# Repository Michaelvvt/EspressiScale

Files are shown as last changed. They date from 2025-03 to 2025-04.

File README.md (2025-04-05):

# EspressiScale

EspressiScale is a minimalist and affordable espresso scale designed to provide accurate measurements along with a built-in timer – perfect for both home and small coffee shop use.

## Features

- **Accurate Weighing:** Provides precise measurements for your espresso brewing.
- **Built-in Timer:** Monitors brewing time to ensure optimal extraction.
- **Minimalist Design:** A simple and modern solution focusing on essential features.
- **Bluetooth Connectivity:** Connect to Gaggiuino or other compatible devices to stream weight and timer data.

## Makerworld
This was also published on [makerworld](https://makerworld.com/en/models/1212476-espressiscale-small-minimalist-espresso-scale#profileId-1227630) for easy 3D printing.

## Bill of Materials (BOM)

| Quantity | Component | Details/Notes |
|---|---|---|
| 1 | [Lilygo T-Touch bar](https://lilygo.cc/products/t-touch-bar?variant=42880705102005) | |
| 1 | Battery | Any 3.7v rechargeable lithium battery (<10x34x48) |
| 1 | [500g Load Cell](https://www.aliexpress.com/item/1005006390450639.html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) | |
| 1 | [HX711](https://www.aliexpress.com/item/1005006293368575.html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) | High precision (available on AliExpress) |
|1 | [USB type C port](https://a.aliexpress.com/_EyspPbK) | Not yet implimented
| 4 | [M3x3.0 Threaded Inserts](https://cnckitchen.store/products/heat-set-insert-m3-x-3-short-version-100-pieces) | (I used CNCkitchen) |
| 2 | M3x10 Screws | |
| 2 | M3x12 Screws | |
| 2 | M3x12 Countersunk Screws | |
| - | Heat Shrink | |

### Optional Components

| Quantity | Component | Details/Notes |
|---|---|---|
| 2 | Extra Heated Inserts | |
| 2 | M3x6 Screws | |

## Installation

1. **PlatformIO setup in Visual Studio:**

   Make sure you have PlatformIO installed in Visual Studio. You'll also need espressif platform installed.
   
3. **Clone the repository:**

   ```bash
   git clone https://github.com/whauu/EspressiScale.git

4. **Navigate to the project folder**

   ```bash
   cd EspressiScale

5. **Open project in PlatformIO**
   
6. **Erase flash**
   
7. **Build filesystem**
   
8. **Upload filesystem**
   
9. **Build**

10. **Upload**

## Usage
**Touch controls:**
- **Left Display:** Starts and stops timer
- **Right Display:** Tares weight and resets timer
  
**Power:**
  - Touch the display anywhere to wake it up
  - The scale will automatically enter deep sleep after 5min with no use

**Bluetooth:**
  - The scale automatically advertises as "EspressiScale" via Bluetooth
  - Compatible with Gaggiuino using the esp-arduino-ble-scales library
  - You can remotely tare the scale, start/stop/reset the timer, and receive weight and timer data

**Update:**
   - Update using "scaleIP"/update
   - Build updated project
   - Upload the firmware.bin file
     <p align="center">
<img src="https://github.com/user-attachments/assets/cd5b869b-26ec-4d18-aa3c-554c78ec7306" alt="Screenshot" />
</p>

[PrettyOTA](https://github.com/LostInCompilation/PrettyOTA.git)

## Gaggiuino Integration

To integrate with Gaggiuino:

1. Make sure your Gaggiuino firmware includes the [esp-arduino-ble-scales](https://github.com/kstam/esp-arduino-ble-scales) library
2. Add the EspressiScale plugin to your Gaggiuino project by copying:
   - `esp-arduino-ble-scales/src/scales/espressiscale.h`
   - `esp-arduino-ble-scales/src/scales/espressiscale.cpp`
3. Add the following to your Gaggiuino initialization code:
   ```cpp
   #include "scales/espressiscale.h"
   
   void setup() {
     // ... other initialization code
     
     // Register the EspressiScale plugin
     EspressiScalesPlugin::apply();
     
     // ... other setup code
   }
   ```
4. Now your Gaggiuino should be able to automatically discover and connect to your EspressiScale

## License
This project is licensed under the MIT License

## Contact
If you have any questions or suggestions, you can:
- Open an issue in the GitHub repository
- Contact me directly at [whauu@espressiscale.com]

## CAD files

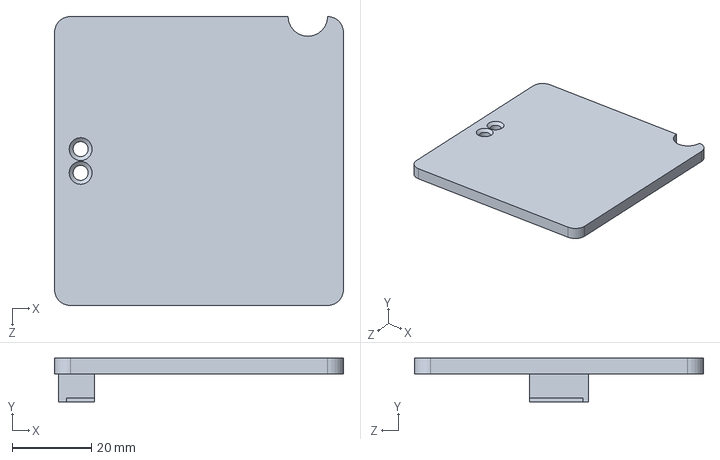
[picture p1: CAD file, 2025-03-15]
3D files/Vekt_innmat.SLDPRT
73.0 x 11.0 x 73.0 mm

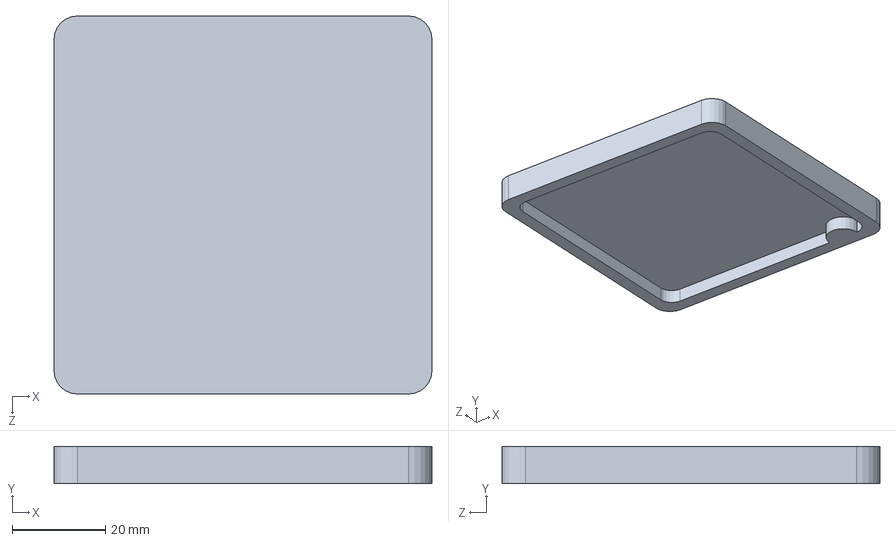
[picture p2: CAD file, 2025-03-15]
3D files/Vekt_mold.SLDPRT
81.0 x 8.00 x 81.0 mm

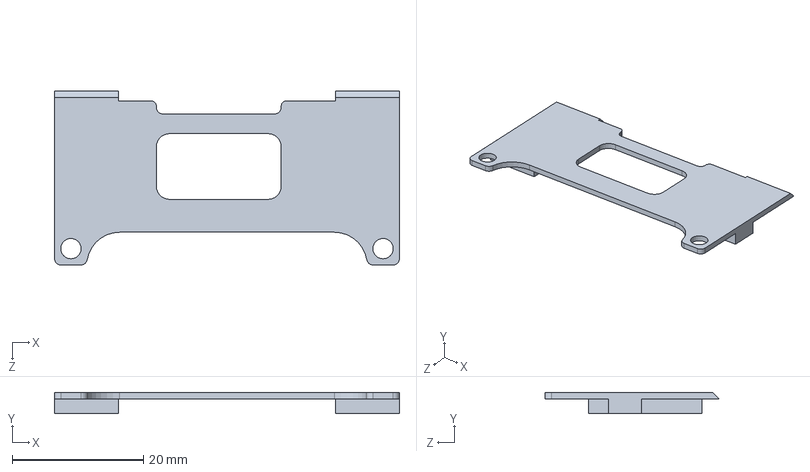
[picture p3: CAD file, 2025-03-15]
3D files/Vekt_bracket.SLDPRT
52.5 x 3.20 x 26.5 mm

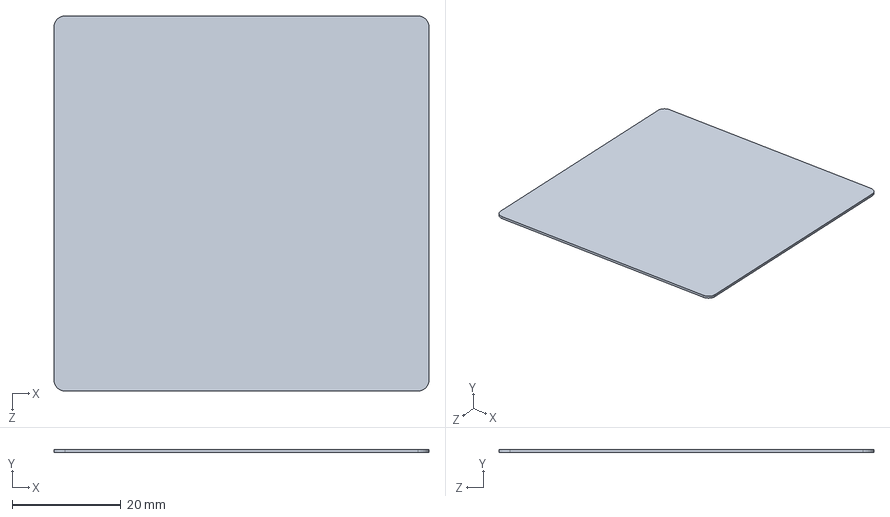
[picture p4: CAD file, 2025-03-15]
3D files/Vekt_matte.SLDPRT
69.0 x 0.6 x 69.0 mm

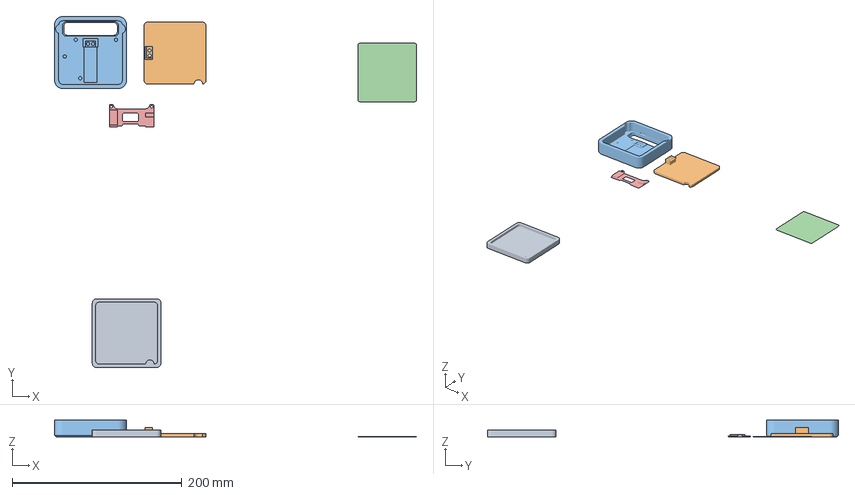
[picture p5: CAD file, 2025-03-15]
3D files/EspressiScale.3mf
426.7 x 413.7 x 20.0 mm
vekt_mould
innmat
Vekt_skall
weight_underpad
latch

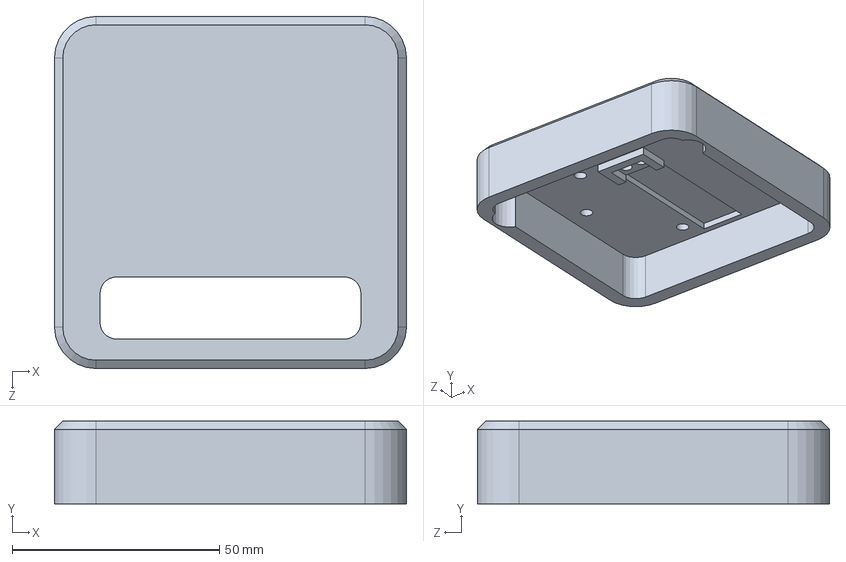
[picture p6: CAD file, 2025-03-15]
3D files/Vekt_skall.SLDPRT
85.0 x 20.0 x 85.0 mm

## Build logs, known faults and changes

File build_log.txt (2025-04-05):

Processing esp32s3box (platform: espressif32; board: esp32s3box; framework: arduino; lib_deps: bogde/HX711@^0.7.5, https://github.com/tzapu/WiFiManager.git, lostincompilation/PrettyOTA@^1.0.2, h2zero/NimBLE-Arduino@^1.4.1; monitor_speed: 921600; board_build.filesystem: littlefs; board_build.partitions: min_spiffs.csv)
--------------------------------------------------------------------------------
CONFIGURATION: https://docs.platformio.org/page/boards/espressif32/esp32s3box.html
PLATFORM: Espressif 32 (6.10.0) > Espressif ESP32-S3-Box
HARDWARE: ESP32S3 240MHz, 320KB RAM, 16MB Flash
DEBUG: Current (cmsis-dap) External (cmsis-dap, esp-bridge, esp-builtin, esp-prog, iot-bus-jtag, jlink, minimodule, olimex-arm-usb-ocd, olimex-arm-usb-ocd-h, olimex-arm-usb-tiny-h, olimex-jtag-tiny, tumpa)
PACKAGES: 
 - framework-arduinoespressif32 @ 3.20017.241212+sha.dcc1105b 
 - tool-esptoolpy @ 1.40501.0 (4.5.1) 
 - toolchain-riscv32-esp @ 8.4.0+2021r2-patch5 
 - toolchain-xtensa-esp32s3 @ 8.4.0+2021r2-patch5
LDF: Library Dependency Finder -> https://bit.ly/configure-pio-ldf
LDF Modes: Finder ~ chain, Compatibility ~ soft
Found 42 compatible libraries
Scanning dependencies...
Warning: Ignored `ESPAsyncWebServer` dependency for `PrettyOTA` library
Warning: Ignored `AsyncTCP` dependency for `ESPAsyncWebServer` library
Warning: Ignored `ESPAsyncTCP` dependency for `ESPAsyncWebServer` library
Warning: Ignored `Hash` dependency for `ESPAsyncWebServer` library
Warning: Ignored `RPAsyncTCP` dependency for `ESPAsyncWebServer` library
Dependency Graph
|-- HX711 @ 0.7.5 (License: Unknown, Path: /Users/michaelvvt/Coffee Project/EspressiScale/.pio/libdeps/esp32s3box/HX711)
|-- WiFiManager @ 2.0.17+sha.32655b7 (License: Unknown, URI: git+https://github.com/tzapu/WiFiManager.git, Path: /Users/michaelvvt/Coffee Project/EspressiScale/.pio/libdeps/esp32s3box/WiFiManager)
|   |-- DNSServer @ 2.0.0 (License: Unknown, Path: /Users/michaelvvt/.platformio/packages/framework-arduinoespressif32/libraries/DNSServer)
|   |   |-- WiFi @ 2.0.0 (License: Unknown, Path: /Users/michaelvvt/.platformio/packages/framework-arduinoespressif32/libraries/WiFi)
|   |-- ESPmDNS @ 2.0.0 (License: Unknown, Path: /Users/michaelvvt/.platformio/packages/framework-arduinoespressif32/libraries/ESPmDNS)
|   |   |-- WiFi @ 2.0.0 (License: Unknown, Path: /Users/michaelvvt/.platformio/packages/framework-arduinoespressif32/libraries/WiFi)
|   |-- Update @ 2.0.0 (License: Unknown, Path: /Users/michaelvvt/.platformio/packages/framework-arduinoespressif32/libraries/Update)
|   |-- WebServer @ 2.0.0 (License: Unknown, Path: /Users/michaelvvt/.platformio/packages/framework-arduinoespressif32/libraries/WebServer)
|   |   |-- WiFi @ 2.0.0 (License: Unknown, Path: /Users/michaelvvt/.platformio/packages/framework-arduinoespressif32/libraries/WiFi)
|   |   |-- FS @ 2.0.0 (License: Unknown, Path: /Users/michaelvvt/.platformio/packages/framework-arduinoespressif32/libraries/FS)
|   |-- WiFi @ 2.0.0 (License: Unknown, Path: /Users/michaelvvt/.platformio/packages/framework-arduinoespressif32/libraries/WiFi)
|-- PrettyOTA @ 1.0.6 (License: MIT, Path: /Users/michaelvvt/Coffee Project/EspressiScale/.pio/libdeps/esp32s3box/PrettyOTA)
|   |-- ArduinoJson @ 7.3.1 (License: Unknown, Path: /Users/michaelvvt/Coffee Project/EspressiScale/.pio/libdeps/esp32s3box/ArduinoJson)
|   |-- ArduinoOTA @ 2.0.0 (License: Unknown, Path: /Users/michaelvvt/.platformio/packages/framework-arduinoespressif32/libraries/ArduinoOTA)
|   |   |-- Update @ 2.0.0 (License: Unknown, Path: /Users/michaelvvt/.platformio/packages/framework-arduinoespressif32/libraries/Update)
|   |   |-- WiFi @ 2.0.0 (License: Unknown, Path: /Users/michaelvvt/.platformio/packages/framework-arduinoespressif32/libraries/WiFi)
|   |   |-- ESPmDNS @ 2.0.0 (License: Unknown, Path: /Users/michaelvvt/.platformio/packages/framework-arduinoespressif32/libraries/ESPmDNS)
|   |   |   |-- WiFi @ 2.0.0 (License: Unknown, Path: /Users/michaelvvt/.platformio/packages/framework-arduinoespressif32/libraries/WiFi)
|   |-- AsyncTCP @ 3.3.8 (License: LGPL-3.0, Path: /Users/michaelvvt/Coffee Project/EspressiScale/.pio/libdeps/esp32s3box/AsyncTCP)
|   |-- ESPAsyncWebServer @ 3.7.4 (License: LGPL-3.0, Path: /Users/michaelvvt/Coffee Project/EspressiScale/.pio/libdeps/esp32s3box/ESPAsyncWebServer)
|   |   |-- AsyncTCP @ 3.3.8 (License: LGPL-3.0, Path: /Users/michaelvvt/Coffee Project/EspressiScale/.pio/libdeps/esp32s3box/AsyncTCP)
|   |   |-- FS @ 2.0.0 (License: Unknown, Path: /Users/michaelvvt/.platformio/packages/framework-arduinoespressif32/libraries/FS)
|   |   |-- WebServer @ 2.0.0 (License: Unknown, Path: /Users/michaelvvt/.platformio/packages/framework-arduinoespressif32/libraries/WebServer)
|   |   |   |-- WiFi @ 2.0.0 (License: Unknown, Path: /Users/michaelvvt/.platformio/packages/framework-arduinoespressif32/libraries/WiFi)
|   |   |   |-- FS @ 2.0.0 (License: Unknown, Path: /Users/michaelvvt/.platformio/packages/framework-arduinoespressif32/libraries/FS)
|   |   |-- WiFi @ 2.0.0 (License: Unknown, Path: /Users/michaelvvt/.platformio/packages/framework-arduinoespressif32/libraries/WiFi)
|   |   |-- ArduinoJson @ 7.3.1 (License: Unknown, Path: /Users/michaelvvt/Coffee Project/EspressiScale/.pio/libdeps/esp32s3box/ArduinoJson)
|-- NimBLE-Arduino @ 1.4.3 (License: Unknown, Path: /Users/michaelvvt/Coffee Project/EspressiScale/.pio/libdeps/esp32s3box/NimBLE-Arduino)
|-- lvgl @ 8.3.0-dev (License: MIT, Path: /Users/michaelvvt/Coffee Project/EspressiScale/lib/lvgl)
|-- SPI @ 2.0.0 (License: Unknown, Path: /Users/michaelvvt/.platformio/packages/framework-arduinoespressif32/libraries/SPI)
|-- TouchLib @ 0.0.2 (License: Unknown, Path: /Users/michaelvvt/Coffee Project/EspressiScale/lib/TouchLib)
|   |-- Wire @ 2.0.0 (License: Unknown, Path: /Users/michaelvvt/.platformio/packages/framework-arduinoespressif32/libraries/Wire)
|-- Wire @ 2.0.0 (License: Unknown, Path: /Users/michaelvvt/.platformio/packages/framework-arduinoespressif32/libraries/Wire)
Building in release mode
xtensa-esp32s3-elf-g++ -o .pio/build/esp32s3box/src/ble_service.cpp.o -c -std=gnu++11 -fexceptions -fno-rtti -Os -mlongcalls -ffunction-sections -fdata-sections -Wno-error=unused-function -Wno-error=unused-variable -Wno-error=deprecated-declarations -Wno-unused-parameter -Wno-sign-compare -ggdb -freorder-blocks -Wwrite-strings -fstack-protector -fstrict-volatile-bitfields -Wno-error=unused-but-set-variable -fno-jump-tables -fno-tree-switch-conversion -MMD -DPLATFORMIO=60118 -DBOARD_HAS_PSRAM -DARDUINO_ESP32_S3_BOX -DARDUINO_USB_MODE=1 -DARDUINO_USB_CDC_ON_BOOT=1 -DHAVE_CONFIG_H -DMBEDTLS_CONFIG_FILE=\"mbedtls/esp_config.h\" -DUNITY_INCLUDE_CONFIG_H -DWITH_POSIX -D_GNU_SOURCE -DIDF_VER=\"v4.4.7-dirty\" -DESP_PLATFORM -D_POSIX_READER_WRITER_LOCKS -DARDUINO_ARCH_ESP32 -DESP32 -DF_CPU=240000000L -DARDUINO=10812 -DARDUINO_VARIANT=\"esp32s3box\" "-DARDUINO_BOARD=\"Espressif ESP32-S3-Box\"" -DARDUINO_PARTITION_min_spiffs -Iinclude -Isrc -Ilib/TouchLib/src -I/Users/michaelvvt/.platformio/packages/framework-arduinoespressif32/libraries/Wire/src -I/Users/michaelvvt/.platformio/packages/framework-arduinoespressif32/libraries/SPI/src -Ilib/lvgl -Ilib/lvgl/src -I.pio/libdeps/esp32s3box/NimBLE-Arduino/src -I.pio/libdeps/esp32s3box/PrettyOTA/src -I.pio/libdeps/esp32s3box/ESPAsyncWebServer/src -I.pio/libdeps/esp32s3box/AsyncTCP/src -I/Users/michaelvvt/.platformio/packages/framework-arduinoespressif32/libraries/ArduinoOTA/src -I.pio/libdeps/esp32s3box/ArduinoJson/src -I.pio/libdeps/esp32s3box/WiFiManager -I/Users/michaelvvt/.platformio/packages/framework-arduinoespressif32/libraries/WebServer/src -I/Users/michaelvvt/.platformio/packages/framework-arduinoespressif32/libraries/FS/src -I/Users/michaelvvt/.platformio/packages/framework-arduinoespressif32/libraries/Update/src -I/Users/michaelvvt/.platformio/packages/framework-arduinoespressif32/libraries/ESPmDNS/src -I/Users/michaelvvt/.platformio/packages/framework-arduinoespressif32/libraries/DNSServer/src -I/Users/michaelvvt/.platformio/packages/framework-arduinoespressif32/libraries/WiFi/src -I.pio/libdeps/esp32s3box/HX711/src -I/Users/michaelvvt/.platformio/packages/framework-arduinoespressif32/tools/sdk/esp32s3/include/newlib/platform_include -I/Users/michaelvvt/.platformio/packages/framework-arduinoespressif32/tools/sdk/esp32s3/include/freertos/include -I/Users/michaelvvt/.platformio/packages/framework-arduinoespressif32/tools/sdk/esp32s3/include/freertos/include/esp_additions/freertos -I/Users/michaelvvt/.platformio/packages/framework-arduinoespressif32/tools/sdk/esp32s3/include/freertos/port/xtensa/include -I/Users/michaelvvt/.platformio/packages/framework-arduinoespressif32/tools/sdk/esp32s3/include/freertos/include/esp_additions -I/Users/michaelvvt/.platformio/packages/framework-arduinoespressif32/tools/sdk/esp32s3/include/esp_hw_support/include -I/Users/michaelvvt/.platformio/packages/framework-arduinoespressif32/tools/sdk/esp32s3/include/esp_hw_support/include/soc -I/Users/michaelvvt/.platformio/packages/framework-arduinoespressif32/tools/sdk/esp32s3/include/esp_hw_support/include/soc/esp32s3 -I/Users/michaelvvt/.platformio/packages/framework-arduinoespressif32/tools/sdk/esp32s3/include/esp_hw_support/port/esp32s3 -I/Users/michaelvvt/.platformio/packages/framework-arduinoespressif32/tools/sdk/esp32s3/include/esp_hw_support/port/esp32s3/private_include -I/Users/michaelvvt/.platformio/packages/framework-arduinoespressif32/tools/sdk/esp32s3/include/heap/include -I/Users/michaelvvt/.platformio/packages/framework-arduinoespressif32/tools/sdk/esp32s3/include/log/include -I/Users/michaelvvt/.platformio/packages/framework-arduinoespressif32/tools/sdk/esp32s3/include/lwip/include/apps -I/Users/michaelvvt/.platformio/packages/framework-arduinoespressif32/tools/sdk/esp32s3/include/lwip/include/apps/sntp -I/Users/michaelvvt/.platformio/packages/framework-arduinoespressif32/tools/sdk/esp32s3/include/lwip/lwip/src/include -I/Users/michaelvvt/.platformio/packages/framework-arduinoespressif32/tools/sdk/esp32s3/include/lwip/port/esp32/include -I/Users/michaelvvt/.platformio/packages/framework-arduinoespressif32/tools/sdk/esp32s3/include/lwip/port/esp32/include/arch -I/Users/michaelvvt/.platformio/packages/framework-arduinoespressif32/tools/sdk/esp32s3/include/soc/include -I/Users/michaelvvt/.platformio/packages/framework-arduinoespressif32/tools/sdk/esp32s3/include/soc/esp32s3 -I/Users/michaelvvt/.platformio/packages/framework-arduinoespressif32/tools/sdk/esp32s3/include/soc/esp32s3/include -I/Users/michaelvvt/.platformio/packages/framework-arduinoespressif32/tools/sdk/esp32s3/include/hal/esp32s3/include -I/Users/michaelvvt/.platformio/packages/framework-arduinoespressif32/tools/sdk/esp32s3/include/hal/include -I/Users/michaelvvt/.platformio/packages/framework-arduinoespressif32/tools/sdk/esp32s3/include/hal/platform_port/include -I/Users/michaelvvt/.platformio/packages/framework-arduinoespressif32/tools/sdk/esp32s3/include/esp_rom/include -I/Users/michaelvvt/.platformio/packages/framework-arduinoespressif32/tools/sdk/esp32s3/include/esp_rom/include/esp32s3 -I/Users/michaelvvt/.platformio/packages/framework-arduinoespressif32/tools/sdk/esp32s3/include/esp_rom/esp32s3 -I/Users/michaelvvt/.platformio/packages/framework-arduinoespressif32/tools/sdk/esp32s3/include/esp_common/include -I/Users/michaelvvt/.platformio/packages/framework-arduinoespressif32/tools/sdk/esp32s3/include/esp_system/include -I/Users/michaelvvt/.platformio/packages/framework-arduinoespressif32/tools/sdk/esp32s3/include/esp_system/port/soc -I/Users/michaelvvt/.platformio/packages/framework-arduinoespressif32/tools/sdk/esp32s3/include/esp_system/port/public_compat -I/Users/michaelvvt/.platformio/packages/framework-arduinoespressif32/tools/sdk/esp32s3/include/xtensa/include -I/Users/michaelvvt/.platformio/packages/framework-arduinoespressif32/tools/sdk/esp32s3/include/xtensa/esp32s3/include -I/Users/michaelvvt/.platformio/packages/framework-arduinoespressif32/tools/sdk/esp32s3/include/driver/include -I/Users/michaelvvt/.platformio/packages/framework-arduinoespressif32/tools/sdk/esp32s3/include/driver/esp32s3/include -I/Users/michaelvvt/.platformio/packages/framework-arduinoespressif32/tools/sdk/esp32s3/include/esp_pm/include -I/Users/michaelvvt/.platformio/packages/framework-arduinoespressif32/tools/sdk/esp32s3/include/esp_ringbuf/include -I/Users/michaelvvt/.platformio/packages/framework-arduinoespressif32/tools/sdk/esp32s3/include/efuse/include -I/Users/michaelvvt/.platformio/packages/framework-arduinoespressif32/tools/sdk/esp32s3/include/efuse/esp32s3/include -I/Users/michaelvvt/.platformio/packages/framework-arduinoespressif32/tools/sdk/esp32s3/include/vfs/include -I/Users/michaelvvt/.platformio/packages/framework-arduinoespressif32/tools/sdk/esp32s3/include/esp_wifi/include -I/Users/michaelvvt/.platformio/packages/framework-arduinoespressif32/tools/sdk/esp32s3/include/esp_event/include -I/Users/michaelvvt/.platformio/packages/framework-arduinoespressif32/tools/sdk/esp32s3/include/esp_netif/include -I/Users/michaelvvt/.platformio/packages/framework-arduinoespressif32/tools/sdk/esp32s3/include/esp_eth/include -I/Users/michaelvvt/.platformio/packages/framework-arduinoespressif32/tools/sdk/esp32s3/include/tcpip_adapter/include -I/Users/michaelvvt/.platformio/packages/framework-arduinoespressif32/tools/sdk/esp32s3/include/esp_phy/include -I/Users/michaelvvt/.platformio/packages/framework-arduinoespressif32/tools/sdk/esp32s3/include/esp_phy/esp32s3/include -I/Users/michaelvvt/.platformio/packages/framework-arduinoespressif32/tools/sdk/esp32s3/include/esp_ipc/include -I/Users/michaelvvt/.platformio/packages/framework-arduinoespressif32/tools/sdk/esp32s3/include/app_trace/include -I/Users/michaelvvt/.platformio/packages/framework-arduinoespressif32/tools/sdk/esp32s3/include/esp_timer/include -I/Users/michaelvvt/.platformio/packages/framework-arduinoespressif32/tools/sdk/esp32s3/include/mbedtls/port/include -I/Users/michaelvvt/.platformio/packages/framework-arduinoespressif32/tools/sdk/esp32s3/include/mbedtls/mbedtls/include -I/Users/michaelvvt/.platformio/packages/framework-arduinoespressif32/tools/sdk/esp32s3/include/mbedtls/esp_crt_bundle/include -I/Users/michaelvvt/.platformio/packages/framework-arduinoespressif32/tools/sdk/esp32s3/include/app_update/include -I/Users/michaelvvt/.platformio/packages/framework-arduinoespressif32/tools/sdk/esp32s3/include/spi_flash/include -I/Users/michaelvvt/.platformio/packages/framework-arduinoespressif32/tools/sdk/esp32s3/include/bootloader_support/include -I/Users/michaelvvt/.platformio/packages/framework-arduinoespressif32/tools/sdk/esp32s3/include/nvs_flash/include -I/Users/michaelvvt/.platformio/packages/framework-arduinoespressif32/tools/sdk/esp32s3/include/pthread/include -I/Users/michaelvvt/.platformio/packages/framework-arduinoespressif32/tools/sdk/esp32s3/include/esp_gdbstub/include -I/Users/michaelvvt/.platformio/packages/framework-arduinoespressif32/tools/sdk/esp32s3/include/esp_gdbstub/xtensa -I/Users/michaelvvt/.platformio/packages/framework-arduinoespressif32/tools/sdk/esp32s3/include/esp_gdbstub/esp32s3 -I/Users/michaelvvt/.platformio/packages/framework-arduinoespressif32/tools/sdk/esp32s3/include/espcoredump/include -I/Users/michaelvvt/.platformio/packages/framework-arduinoespressif32/tools/sdk/esp32s3/include/espcoredump/include/port/xtensa -I/Users/michaelvvt/.platformio/packages/framework-arduinoespressif32/tools/sdk/esp32s3/include/wpa_supplicant/include -I/Users/michaelvvt/.platformio/packages/framework-arduinoespressif32/tools/sdk/esp32s3/include/wpa_supplicant/port/include -I/Users/michaelvvt/.platformio/packages/framework-arduinoespressif32/tools/sdk/esp32s3/include/wpa_supplicant/esp_supplicant/include -I/Users/michaelvvt/.platformio/packages/framework-arduinoespressif32/tools/sdk/esp32s3/include/ieee802154/include -I/Users/michaelvvt/.platformio/packages/framework-arduinoespressif32/tools/sdk/esp32s3/include/console -I/Users/michaelvvt/.platformio/packages/framework-arduinoespressif32/tools/sdk/esp32s3/include/asio/asio/asio/include -I/Users/michaelvvt/.platformio/packages/framework-arduinoespressif32/tools/sdk/esp32s3/include/asio/port/include -I/Users/michaelvvt/.platformio/packages/framework-arduinoespressif32/tools/sdk/esp32s3/include/bt/common/osi/include -I/Users/michaelvvt/.platformio/packages/framework-arduinoespressif32/tools/sdk/esp32s3/include/bt/include/esp32c3/include -I/Users/michaelvvt/.platformio/packages/framework-arduinoespressif32/tools/sdk/esp32s3/include/bt/common/api/include/api -I/Users/michaelvvt/.platformio/packages/framework-arduinoespressif32/tools/sdk/esp32s3/include/bt/common/btc/profile/esp/blufi/include -I/Users/michaelvvt/.platformio/packages/framework-arduinoespressif32/tools/sdk/esp32s3/include/bt/common/btc/profile/esp/include -I/Users/michaelvvt/.platformio/packages/framework-arduinoespressif32/tools/sdk/esp32s3/include/bt/host/bluedroid/api/include/api -I/Users/michaelvvt/.platformio/packages/framework-arduinoespressif32/tools/sdk/esp32s3/include/bt/esp_ble_mesh/mesh_common/include -I/Users/michaelvvt/.platformio/packages/framework-arduinoespressif32/tools/sdk/esp32s3/include/bt/esp_ble_mesh/mesh_common/tinycrypt/include -I/Users/michaelvvt/.platformio/packages/framework-arduinoespressif32/tools/sdk/esp32s3/include/bt/esp_ble_mesh/mesh_core -I/Users/michaelvvt/.platformio/packages/framework-arduinoespressif32/tools/sdk/esp32s3/include/bt/esp_ble_mesh/mesh_core/include -I/Users/michaelvvt/.platformio/packages/framework-arduinoespressif32/tools/sdk/esp32s3/include/bt/esp_ble_mesh/mesh_core/storage -I/Users/michaelvvt/.platformio/packages/framework-arduinoespressif32/tools/sdk/esp32s3/include/bt/esp_ble_mesh/btc/include -I/Users/michaelvvt/.platformio/packages/framework-arduinoespressif32/tools/sdk/esp32s3/include/bt/esp_ble_mesh/mesh_models/common/include -I/Users/michaelvvt/.platformio/packages/framework-arduinoespressif32/tools/sdk/esp32s3/include/bt/esp_ble_mesh/mesh_models/client/include -I/Users/michaelvvt/.platformio/packages/framework-arduinoespressif32/tools/sdk/esp32s3/include/bt/esp_ble_mesh/mesh_models/server/include -I/Users/michaelvvt/.platformio/packages/framework-arduinoespressif32/tools/sdk/esp32s3/include/bt/esp_ble_mesh/api/core/include -I/Users/michaelvvt/.platformio/packages/framework-arduinoespressif32/tools/sdk/esp32s3/include/bt/esp_ble_mesh/api/models/include -I/Users/michaelvvt/.platformio/packages/framework-arduinoespressif32/tools/sdk/esp32s3/include/bt/esp_ble_mesh/api -I/Users/michaelvvt/.platformio/packages/framework-arduinoespressif32/tools/sdk/esp32s3/include/cbor/port/include -I/Users/michaelvvt/.platformio/packages/framework-arduinoespressif32/tools/sdk/esp32s3/include/unity/include -I/Users/michaelvvt/.platformio/packages/framework-arduinoespressif32/tools/sdk/esp32s3/include/unity/unity/src -I/Users/michaelvvt/.platformio/packages/framework-arduinoespressif32/tools/sdk/esp32s3/include/cmock/CMock/src -I/Users/michaelvvt/.platformio/packages/framework-arduinoespressif32/tools/sdk/esp32s3/include/coap/port/include -I/Users/michaelvvt/.platformio/packages/framework-arduinoespressif32/tools/sdk/esp32s3/include/coap/libcoap/include -I/Users/michaelvvt/.platformio/packages/framework-arduinoespressif32/tools/sdk/esp32s3/include/nghttp/port/include -I/Users/michaelvvt/.platformio/packages/framework-arduinoespressif32/tools/sdk/esp32s3/include/nghttp/nghttp2/lib/includes -I/Users/michaelvvt/.platformio/packages/framework-arduinoespressif32/tools/sdk/esp32s3/include/esp-tls -I/Users/michaelvvt/.platformio/packages/framework-arduinoespressif32/tools/sdk/esp32s3/include/esp-tls/esp-tls-crypto -I/Users/michaelvvt/.platformio/packages/framework-arduinoespressif32/tools/sdk/esp32s3/include/esp_adc_cal/include -I/Users/michaelvvt/.platformio/packages/framework-arduinoespressif32/tools/sdk/esp32s3/include/esp_hid/include -I/Users/michaelvvt/.platformio/packages/framework-arduinoespressif32/tools/sdk/esp32s3/include/tcp_transport/include -I/Users/michaelvvt/.platformio/packages/framework-arduinoespressif32/tools/sdk/esp32s3/include/esp_http_client/include -I/Users/michaelvvt/.platformio/packages/framework-arduinoespressif32/tools/sdk/esp32s3/include/esp_http_server/include -I/Users/michaelvvt/.platformio/packages/framework-arduinoespressif32/tools/sdk/esp32s3/include/esp_https_ota/include -I/Users/michaelvvt/.platformio/packages/framework-arduinoespressif32/tools/sdk/esp32s3/include/esp_https_server/include -I/Users/michaelvvt/.platformio/packages/framework-arduinoespressif32/tools/sdk/esp32s3/include/esp_lcd/include -I/Users/michaelvvt/.platformio/packages/framework-arduinoespressif32/tools/sdk/esp32s3/include/esp_lcd/interface -I/Users/michaelvvt/.platformio/packages/framework-arduinoespressif32/tools/sdk/esp32s3/include/protobuf-c/protobuf-c -I/Users/michaelvvt/.platformio/packages/framework-arduinoespressif32/tools/sdk/esp32s3/include/protocomm/include/common -I/Users/michaelvvt/.platformio/packages/framework-arduinoespressif32/tools/sdk/esp32s3/include/protocomm/include/security -I/Users/michaelvvt/.platformio/packages/framework-arduinoespressif32/tools/sdk/esp32s3/include/protocomm/include/transports -I/Users/michaelvvt/.platformio/packages/framework-arduinoespressif32/tools/sdk/esp32s3/include/mdns/include -I/Users/michaelvvt/.platformio/packages/framework-arduinoespressif32/tools/sdk/esp32s3/include/esp_local_ctrl/include -I/Users/michaelvvt/.platformio/packages/framework-arduinoespressif32/tools/sdk/esp32s3/include/sdmmc/include -I/Users/michaelvvt/.platformio/packages/framework-arduinoespressif32/tools/sdk/esp32s3/include/esp_serial_slave_link/include -I/Users/michaelvvt/.platformio/packages/framework-arduinoespressif32/tools/sdk/esp32s3/include/esp_websocket_client/include -I/Users/michaelvvt/.platformio/packages/framework-arduinoespressif32/tools/sdk/esp32s3/include/expat/expat/expat/lib -I/Users/michaelvvt/.platformio/packages/framework-arduinoespressif32/tools/sdk/esp32s3/include/expat/port/include -I/Users/michaelvvt/.platformio/packages/framework-arduinoespressif32/tools/sdk/esp32s3/include/wear_levelling/include -I/Users/michaelvvt/.platformio/packages/framework-arduinoespressif32/tools/sdk/esp32s3/include/fatfs/diskio -I/Users/michaelvvt/.platformio/packages/framework-arduinoespressif32/tools/sdk/esp32s3/include/fatfs/vfs -I/Users/michaelvvt/.platformio/packages/framework-arduinoespressif32/tools/sdk/esp32s3/include/fatfs/src -I/Users/michaelvvt/.platformio/packages/framework-arduinoespressif32/tools/sdk/esp32s3/include/freemodbus/freemodbus/common/include -I/Users/michaelvvt/.platformio/packages/framework-arduinoespressif32/tools/sdk/esp32s3/include/idf_test/include -I/Users/michaelvvt/.platformio/packages/framework-arduinoespressif32/tools/sdk/esp32s3/include/idf_test/include/esp32s3 -I/Users/michaelvvt/.platformio/packages/framework-arduinoespressif32/tools/sdk/esp32s3/include/jsmn/include -I/Users/michaelvvt/.platformio/packages/framework-arduinoespressif32/tools/sdk/esp32s3/include/json/cJSON -I/Users/michaelvvt/.platformio/packages/framework-arduinoespressif32/tools/sdk/esp32s3/include/libsodium/libsodium/src/libsodium/include -I/Users/michaelvvt/.platformio/packages/framework-arduinoespressif32/tools/sdk/esp32s3/include/libsodium/port_include -I/Users/michaelvvt/.platformio/packages/framework-arduinoespressif32/tools/sdk/esp32s3/include/mqtt/esp-mqtt/include -I/Users/michaelvvt/.platformio/packages/framework-arduinoespressif32/tools/sdk/esp32s3/include/openssl/include -I/Users/michaelvvt/.platformio/packages/framework-arduinoespressif32/tools/sdk/esp32s3/include/perfmon/include -I/Users/michaelvvt/.platformio/packages/framework-arduinoespressif32/tools/sdk/esp32s3/include/spiffs/include -I/Users/michaelvvt/.platformio/packages/framework-arduinoespressif32/tools/sdk/esp32s3/include/usb/include -I/Users/michaelvvt/.platformio/packages/framework-arduinoespressif32/tools/sdk/esp32s3/include/ulp/include -I/Users/michaelvvt/.platformio/packages/framework-arduinoespressif32/tools/sdk/esp32s3/include/wifi_provisioning/include -I/Users/michaelvvt/.platformio/packages/framework-arduinoespressif32/tools/sdk/esp32s3/include/rmaker_common/include -I/Users/michaelvvt/.platformio/packages/framework-arduinoespressif32/tools/sdk/esp32s3/include/esp_diagnostics/include -I/Users/michaelvvt/.platformio/packages/framework-arduinoespressif32/tools/sdk/esp32s3/include/rtc_store/include -I/Users/michaelvvt/.platformio/packages/framework-arduinoespressif32/tools/sdk/esp32s3/include/esp_insights/include -I/Users/michaelvvt/.platformio/packages/framework-arduinoespressif32/tools/sdk/esp32s3/include/json_parser/upstream/include -I/Users/michaelvvt/.platformio/packages/framework-arduinoespressif32/tools/sdk/esp32s3/include/json_parser/upstream -I/Users/michaelvvt/.platformio/packages/framework-arduinoespressif32/tools/sdk/esp32s3/include/json_generator/upstream -I/Users/michaelvvt/.platformio/packages/framework-arduinoespressif32/tools/sdk/esp32s3/include/esp_schedule/include -I/Users/michaelvvt/.platformio/packages/framework-arduinoespressif32/tools/sdk/esp32s3/include/espressif__esp_secure_cert_mgr/include -I/Users/michaelvvt/.platformio/packages/framework-arduinoespressif32/tools/sdk/esp32s3/include/esp_rainmaker/include -I/Users/michaelvvt/.platformio/packages/framework-arduinoespressif32/tools/sdk/esp32s3/include/gpio_button/button/include -I/Users/michaelvvt/.platformio/packages/framework-arduinoespressif32/tools/sdk/esp32s3/include/qrcode/include -I/Users/michaelvvt/.platformio/packages/framework-arduinoespressif32/tools/sdk/esp32s3/include/ws2812_led -I/Users/michaelvvt/.platformio/packages/framework-arduinoespressif32/tools/sdk/esp32s3/include/freertos/include/freertos -I/Users/michaelvvt/.platformio/packages/framework-arduinoespressif32/tools/sdk/esp32s3/include/arduino_tinyusb/tinyusb/src -I/Users/michaelvvt/.platformio/packages/framework-arduinoespressif32/tools/sdk/esp32s3/include/arduino_tinyusb/include -I/Users/michaelvvt/.platformio/packages/framework-arduinoespressif32/tools/sdk/esp32s3/include/esp_littlefs/include -I/Users/michaelvvt/.platformio/packages/framework-arduinoespressif32/tools/sdk/esp32s3/include/esp-dl/include -I/Users/michaelvvt/.platformio/packages/framework-arduinoespressif32/tools/sdk/esp32s3/include/esp-dl/include/tool -I/Users/michaelvvt/.platformio/packages/framework-arduinoespressif32/tools/sdk/esp32s3/include/esp-dl/include/typedef -I/Users/michaelvvt/.platformio/packages/framework-arduinoespressif32/tools/sdk/esp32s3/include/esp-dl/include/image -I/Users/michaelvvt/.platformio/packages/framework-arduinoespressif32/tools/sdk/esp32s3/include/esp-dl/include/math -I/Users/michaelvvt/.platformio/packages/framework-arduinoespressif32/tools/sdk/esp32s3/include/esp-dl/include/nn -I/Users/michaelvvt/.platformio/packages/framework-arduinoespressif32/tools/sdk/esp32s3/include/esp-dl/include/layer -I/Users/michaelvvt/.platformio/packages/framework-arduinoespressif32/tools/sdk/esp32s3/include/esp-dl/include/detect -I/Users/michaelvvt/.platformio/packages/framework-arduinoespressif32/tools/sdk/esp32s3/include/esp-dl/include/model_zoo -I/Users/michaelvvt/.platformio/packages/framework-arduinoespressif32/tools/sdk/esp32s3/include/esp32-camera/driver/include -I/Users/michaelvvt/.platformio/packages/framework-arduinoespressif32/tools/sdk/esp32s3/include/esp32-camera/conversions/include -I/Users/michaelvvt/.platformio/packages/framework-arduinoespressif32/tools/sdk/esp32s3/include/espressif__esp-dsp/modules/dotprod/include -I/Users/michaelvvt/.platformio/packages/framework-arduinoespressif32/tools/sdk/esp32s3/include/espressif__esp-dsp/modules/support/include -I/Users/michaelvvt/.platformio/packages/framework-arduinoespressif32/tools/sdk/esp32s3/include/espressif__esp-dsp/modules/support/mem/include -I/Users/michaelvvt/.platformio/packages/framework-arduinoespressif32/tools/sdk/esp32s3/include/espressif__esp-dsp/modules/windows/include -I/Users/michaelvvt/.platformio/packages/framework-arduinoespressif32/tools/sdk/esp32s3/include/espressif__esp-dsp/modules/windows/hann/include -I/Users/michaelvvt/.platformio/packages/framework-arduinoespressif32/tools/sdk/esp32s3/include/espressif__esp-dsp/modules/windows/blackman/include -I/Users/michaelvvt/.platformio/packages/framework-arduinoespressif32/tools/sdk/esp32s3/include/espressif__esp-dsp/modules/windows/blackman_harris/include -I/Users/michaelvvt/.platformio/packages/framework-arduinoespressif32/tools/sdk/esp32s3/include/espressif__esp-dsp/modules/windows/blackman_nuttall/include -I/Users/michaelvvt/.platformio/packages/framework-arduinoespressif32/tools/sdk/esp32s3/include/espressif__esp-dsp/modules/windows/nuttall/include -I/Users/michaelvvt/.platformio/packages/framework-arduinoespressif32/tools/sdk/esp32s3/include/espressif__esp-dsp/modules/windows/flat_top/include -I/Users/michaelvvt/.platformio/packages/framework-arduinoespressif32/tools/sdk/esp32s3/include/espressif__esp-dsp/modules/iir/include -I/Users/michaelvvt/.platformio/packages/framework-arduinoespressif32/tools/sdk/esp32s3/include/espressif__esp-dsp/modules/fir/include -I/Users/michaelvvt/.platformio/packages/framework-arduinoespressif32/tools/sdk/esp32s3/include/espressif__esp-dsp/modules/math/include -I/Users/michaelvvt/.platformio/packages/framework-arduinoespressif32/tools/sdk/esp32s3/include/espressif__esp-dsp/modules/math/add/include -I/Users/michaelvvt/.platformio/packages/framework-arduinoespressif32/tools/sdk/esp32s3/include/espressif__esp-dsp/modules/math/sub/include -I/Users/michaelvvt/.platformio/packages/framework-arduinoespressif32/tools/sdk/esp32s3/include/espressif__esp-dsp/modules/math/mul/include -I/Users/michaelvvt/.platformio/packages/framework-arduinoespressif32/tools/sdk/esp32s3/include/espressif__esp-dsp/modules/math/addc/include -I/Users/michaelvvt/.platformio/packages/framework-arduinoespressif32/tools/sdk/esp32s3/include/espressif__esp-dsp/modules/math/mulc/include -I/Users/michaelvvt/.platformio/packages/framework-arduinoespressif32/tools/sdk/esp32s3/include/espressif__esp-dsp/modules/math/sqrt/include -I/Users/michaelvvt/.platformio/packages/framework-arduinoespressif32/tools/sdk/esp32s3/include/espressif__esp-dsp/modules/matrix/mul/include -I/Users/michaelvvt/.platformio/packages/framework-arduinoespressif32/tools/sdk/esp32s3/include/espressif__esp-dsp/modules/matrix/add/include -I/Users/michaelvvt/.platformio/packages/framework-arduinoespressif32/tools/sdk/esp32s3/include/espressif__esp-dsp/modules/matrix/addc/include -I/Users/michaelvvt/.platformio/packages/framework-arduinoespressif32/tools/sdk/esp32s3/include/espressif__esp-dsp/modules/matrix/mulc/include -I/Users/michaelvvt/.platformio/packages/framework-arduinoespressif32/tools/sdk/esp32s3/include/espressif__esp-dsp/modules/matrix/sub/include -I/Users/michaelvvt/.platformio/packages/framework-arduinoespressif32/tools/sdk/esp32s3/include/espressif__esp-dsp/modules/matrix/include -I/Users/michaelvvt/.platformio/packages/framework-arduinoespressif32/tools/sdk/esp32s3/include/espressif__esp-dsp/modules/fft/include -I/Users/michaelvvt/.platformio/packages/framework-arduinoespressif32/tools/sdk/esp32s3/include/espressif__esp-dsp/modules/dct/include -I/Users/michaelvvt/.platformio/packages/framework-arduinoespressif32/tools/sdk/esp32s3/include/espressif__esp-dsp/modules/conv/include -I/Users/michaelvvt/.platformio/packages/framework-arduinoespressif32/tools/sdk/esp32s3/include/espressif__esp-dsp/modules/common/include -I/Users/michaelvvt/.platformio/packages/framework-arduinoespressif32/tools/sdk/esp32s3/include/espressif__esp-dsp/modules/matrix/mul/test/include -I/Users/michaelvvt/.platformio/packages/framework-arduinoespressif32/tools/sdk/esp32s3/include/espressif__esp-dsp/modules/kalman/ekf/include -I/Users/michaelvvt/.platformio/packages/framework-arduinoespressif32/tools/sdk/esp32s3/include/espressif__esp-dsp/modules/kalman/ekf_imu13states/include -I/Users/michaelvvt/.platformio/packages/framework-arduinoespressif32/tools/sdk/esp32s3/include/fb_gfx/include -I/Users/michaelvvt/.platformio/packages/framework-arduinoespressif32/tools/sdk/esp32s3/qio_opi/include -I/Users/michaelvvt/.platformio/packages/framework-arduinoespressif32/cores/esp32 -I/Users/michaelvvt/.platformio/packages/framework-arduinoespressif32/variants/esp32s3box src/ble_service.cpp
xtensa-esp32s3-elf-g++ -o .pio/build/esp32s3box/src/main.cpp.o -c -std=gnu++11 -fexceptions -fno-rtti -Os -mlongcalls -ffunction-sections -fdata-sections -Wno-error=unused-function -Wno-error=unused-variable -Wno-error=deprecated-declarations -Wno-unused-parameter -Wno-sign-compare -ggdb -freorder-blocks -Wwrite-strings -fstack-protector -fstrict-volatile-bitfields -Wno-error=unused-but-set-variable -fno-jump-tables -fno-tree-switch-conversion -MMD -DPLATFORMIO=60118 -DBOARD_HAS_PSRAM -DARDUINO_ESP32_S3_BOX -DARDUINO_USB_MODE=1 -DARDUINO_USB_CDC_ON_BOOT=1 -DHAVE_CONFIG_H -DMBEDTLS_CONFIG_FILE=\"mbedtls/esp_config.h\" -DUNITY_INCLUDE_CONFIG_H -DWITH_POSIX -D_GNU_SOURCE -DIDF_VER=\"v4.4.7-dirty\" -DESP_PLATFORM -D_POSIX_READER_WRITER_LOCKS -DARDUINO_ARCH_ESP32 -DESP32 -DF_CPU=240000000L -DARDUINO=10812 -DARDUINO_VARIANT=\"esp32s3box\" "-DARDUINO_BOARD=\"Espressif ESP32-S3-Box\"" -DARDUINO_PARTITION_min_spiffs -Iinclude -Isrc -Ilib/TouchLib/src -I/Users/michaelvvt/.platformio/packages/framework-arduinoespressif32/libraries/Wire/src -I/Users/michaelvvt/.platformio/packages/framework-arduinoespressif32/libraries/SPI/src -Ilib/lvgl -Ilib/lvgl/src -I.pio/libdeps/esp32s3box/NimBLE-Arduino/src -I.pio/libdeps/esp32s3box/PrettyOTA/src -I.pio/libdeps/esp32s3box/ESPAsyncWebServer/src -I.pio/libdeps/esp32s3box/AsyncTCP/src -I/Users/michaelvvt/.platformio/packages/framework-arduinoespressif32/libraries/ArduinoOTA/src -I.pio/libdeps/esp32s3box/ArduinoJson/src -I.pio/libdeps/esp32s3box/WiFiManager -I/Users/michaelvvt/.platformio/packages/framework-arduinoespressif32/libraries/WebServer/src -I/Users/michaelvvt/.platformio/packages/framework-arduinoespressif32/libraries/FS/src -I/Users/michaelvvt/.platformio/packages/framework-arduinoespressif32/libraries/Update/src -I/Users/michaelvvt/.platformio/packages/framework-arduinoespressif32/libraries/ESPmDNS/src -I/Users/michaelvvt/.platformio/packages/framework-arduinoespressif32/libraries/DNSServer/src -I/Users/michaelvvt/.platformio/packages/framework-arduinoespressif32/libraries/WiFi/src -I.pio/libdeps/esp32s3box/HX711/src -I/Users/michaelvvt/.platformio/packages/framework-arduinoespressif32/tools/sdk/esp32s3/include/newlib/platform_include -I/Users/michaelvvt/.platformio/packages/framework-arduinoespressif32/tools/sdk/esp32s3/include/freertos/include -I/Users/michaelvvt/.platformio/packages/framework-arduinoespressif32/tools/sdk/esp32s3/include/freertos/include/esp_additions/freertos -I/Users/michaelvvt/.platformio/packages/framework-arduinoespressif32/tools/sdk/esp32s3/include/freertos/port/xtensa/include -I/Users/michaelvvt/.platformio/packages/framework-arduinoespressif32/tools/sdk/esp32s3/include/freertos/include/esp_additions -I/Users/michaelvvt/.platformio/packages/framework-arduinoespressif32/tools/sdk/esp32s3/include/esp_hw_support/include -I/Users/michaelvvt/.platformio/packages/framework-arduinoespressif32/tools/sdk/esp32s3/include/esp_hw_support/include/soc -I/Users/michaelvvt/.platformio/packages/framework-arduinoespressif32/tools/sdk/esp32s3/include/esp_hw_support/include/soc/esp32s3 -I/Users/michaelvvt/.platformio/packages/framework-arduinoespressif32/tools/sdk/esp32s3/include/esp_hw_support/port/esp32s3 -I/Users/michaelvvt/.platformio/packages/framework-arduinoespressif32/tools/sdk/esp32s3/include/esp_hw_support/port/esp32s3/private_include -I/Users/michaelvvt/.platformio/packages/framework-arduinoespressif32/tools/sdk/esp32s3/include/heap/include -I/Users/michaelvvt/.platformio/packages/framework-arduinoespressif32/tools/sdk/esp32s3/include/log/include -I/Users/michaelvvt/.platformio/packages/framework-arduinoespressif32/tools/sdk/esp32s3/include/lwip/include/apps -I/Users/michaelvvt/.platformio/packages/framework-arduinoespressif32/tools/sdk/esp32s3/include/lwip/include/apps/sntp -I/Users/michaelvvt/.platformio/packages/framework-arduinoespressif32/tools/sdk/esp32s3/include/lwip/lwip/src/include -I/Users/michaelvvt/.platformio/packages/framework-arduinoespressif32/tools/sdk/esp32s3/include/lwip/port/esp32/include -I/Users/michaelvvt/.platformio/packages/framework-arduinoespressif32/tools/sdk/esp32s3/include/lwip/port/esp32/include/arch -I/Users/michaelvvt/.platformio/packages/framework-arduinoespressif32/tools/sdk/esp32s3/include/soc/include -I/Users/michaelvvt/.platformio/packages/framework-arduinoespressif32/tools/sdk/esp32s3/include/soc/esp32s3 -I/Users/michaelvvt/.platformio/packages/framework-arduinoespressif32/tools/sdk/esp32s3/include/soc/esp32s3/include -I/Users/michaelvvt/.platformio/packages/framework-arduinoespressif32/tools/sdk/esp32s3/include/hal/esp32s3/include -I/Users/michaelvvt/.platformio/packages/framework-arduinoespressif32/tools/sdk/esp32s3/include/hal/include -I/Users/michaelvvt/.platformio/packages/framework-arduinoespressif32/tools/sdk/esp32s3/include/hal/platform_port/include -I/Users/michaelvvt/.platformio/packages/framework-arduinoespressif32/tools/sdk/esp32s3/include/esp_rom/include -I/Users/michaelvvt/.platformio/packages/framework-arduinoespressif32/tools/sdk/esp32s3/include/esp_rom/include/esp32s3 -I/Users/michaelvvt/.platformio/packages/framework-arduinoespressif32/tools/sdk/esp32s3/include/esp_rom/esp32s3 -I/Users/michaelvvt/.platformio/packages/framework-arduinoespressif32/tools/sdk/esp32s3/include/esp_common/include -I/Users/michaelvvt/.platformio/packages/framework-arduinoespressif32/tools/sdk/esp32s3/include/esp_system/include -I/Users/michaelvvt/.platformio/packages/framework-arduinoespressif32/tools/sdk/esp32s3/include/esp_system/port/soc -I/Users/michaelvvt/.platformio/packages/framework-arduinoespressif32/tools/sdk/esp32s3/include/esp_system/port/public_compat -I/Users/michaelvvt/.platformio/packages/framework-arduinoespressif32/tools/sdk/esp32s3/include/xtensa/include -I/Users/michaelvvt/.platformio/packages/framework-arduinoespressif32/tools/sdk/esp32s3/include/xtensa/esp32s3/include -I/Users/michaelvvt/.platformio/packages/framework-arduinoespressif32/tools/sdk/esp32s3/include/driver/include -I/Users/michaelvvt/.platformio/packages/framework-arduinoespressif32/tools/sdk/esp32s3/include/driver/esp32s3/include -I/Users/michaelvvt/.platformio/packages/framework-arduinoespressif32/tools/sdk/esp32s3/include/esp_pm/include -I/Users/michaelvvt/.platformio/packages/framework-arduinoespressif32/tools/sdk/esp32s3/include/esp_ringbuf/include -I/Users/michaelvvt/.platformio/packages/framework-arduinoespressif32/tools/sdk/esp32s3/include/efuse/include -I/Users/michaelvvt/.platformio/packages/framework-arduinoespressif32/tools/sdk/esp32s3/include/efuse/esp32s3/include -I/Users/michaelvvt/.platformio/packages/framework-arduinoespressif32/tools/sdk/esp32s3/include/vfs/include -I/Users/michaelvvt/.platformio/packages/framework-arduinoespressif32/tools/sdk/esp32s3/include/esp_wifi/include -I/Users/michaelvvt/.platformio/packages/framework-arduinoespressif32/tools/sdk/esp32s3/include/esp_event/include -I/Users/michaelvvt/.platformio/packages/framework-arduinoespressif32/tools/sdk/esp32s3/include/esp_netif/include -I/Users/michaelvvt/.platformio/packages/framework-arduinoespressif32/tools/sdk/esp32s3/include/esp_eth/include -I/Users/michaelvvt/.platformio/packages/framework-arduinoespressif32/tools/sdk/esp32s3/include/tcpip_adapter/include -I/Users/michaelvvt/.platformio/packages/framework-arduinoespressif32/tools/sdk/esp32s3/include/esp_phy/include -I/Users/michaelvvt/.platformio/packages/framework-arduinoespressif32/tools/sdk/esp32s3/include/esp_phy/esp32s3/include -I/Users/michaelvvt/.platformio/packages/framework-arduinoespressif32/tools/sdk/esp32s3/include/esp_ipc/include -I/Users/michaelvvt/.platformio/packages/framework-arduinoespressif32/tools/sdk/esp32s3/include/app_trace/include -I/Users/michaelvvt/.platformio/packages/framework-arduinoespressif32/tools/sdk/esp32s3/include/esp_timer/include -I/Users/michaelvvt/.platformio/packages/framework-arduinoespressif32/tools/sdk/esp32s3/include/mbedtls/port/include -I/Users/michaelvvt/.platformio/packages/framework-arduinoespressif32/tools/sdk/esp32s3/include/mbedtls/mbedtls/include -I/Users/michaelvvt/.platformio/packages/framework-arduinoespressif32/tools/sdk/esp32s3/include/mbedtls/esp_crt_bundle/include -I/Users/michaelvvt/.platformio/packages/framework-arduinoespressif32/tools/sdk/esp32s3/include/app_update/include -I/Users/michaelvvt/.platformio/packages/framework-arduinoespressif32/tools/sdk/esp32s3/include/spi_flash/include -I/Users/michaelvvt/.platformio/packages/framework-arduinoespressif32/tools/sdk/esp32s3/include/bootloader_support/include -I/Users/michaelvvt/.platformio/packages/framework-arduinoespressif32/tools/sdk/esp32s3/include/nvs_flash/include -I/Users/michaelvvt/.platformio/packages/framework-arduinoespressif32/tools/sdk/esp32s3/include/pthread/include -I/Users/michaelvvt/.platformio/packages/framework-arduinoespressif32/tools/sdk/esp32s3/include/esp_gdbstub/include -I/Users/michaelvvt/.platformio/packages/framework-arduinoespressif32/tools/sdk/esp32s3/include/esp_gdbstub/xtensa -I/Users/michaelvvt/.platformio/packages/framework-arduinoespressif32/tools/sdk/esp32s3/include/esp_gdbstub/esp32s3 -I/Users/michaelvvt/.platformio/packages/framework-arduinoespressif32/tools/sdk/esp32s3/include/espcoredump/include -I/Users/michaelvvt/.platformio/packages/framework-arduinoespressif32/tools/sdk/esp32s3/include/espcoredump/include/port/xtensa -I/Users/michaelvvt/.platformio/packages/framework-arduinoespressif32/tools/sdk/esp32s3/include/wpa_supplicant/include -I/Users/michaelvvt/.platformio/packages/framework-arduinoespressif32/tools/sdk/esp32s3/include/wpa_supplicant/port/include -I/Users/michaelvvt/.platformio/packages/framework-arduinoespressif32/tools/sdk/esp32s3/include/wpa_supplicant/esp_supplicant/include -I/Users/michaelvvt/.platformio/packages/framework-arduinoespressif32/tools/sdk/esp32s3/include/ieee802154/include -I/Users/michaelvvt/.platformio/packages/framework-arduinoespressif32/tools/sdk/esp32s3/include/console -I/Users/michaelvvt/.platformio/packages/framework-arduinoespressif32/tools/sdk/esp32s3/include/asio/asio/asio/include -I/Users/michaelvvt/.platformio/packages/framework-arduinoespressif32/tools/sdk/esp32s3/include/asio/port/include -I/Users/michaelvvt/.platformio/packages/framework-arduinoespressif32/tools/sdk/esp32s3/include/bt/common/osi/include -I/Users/michaelvvt/.platformio/packages/framework-arduinoespressif32/tools/sdk/esp32s3/include/bt/include/esp32c3/include -I/Users/michaelvvt/.platformio/packages/framework-arduinoespressif32/tools/sdk/esp32s3/include/bt/common/api/include/api -I/Users/michaelvvt/.platformio/packages/framework-arduinoespressif32/tools/sdk/esp32s3/include/bt/common/btc/profile/esp/blufi/include -I/Users/michaelvvt/.platformio/packages/framework-arduinoespressif32/tools/sdk/esp32s3/include/bt/common/btc/profile/esp/include -I/Users/michaelvvt/.platformio/packages/framework-arduinoespressif32/tools/sdk/esp32s3/include/bt/host/bluedroid/api/include/api -I/Users/michaelvvt/.platformio/packages/framework-arduinoespressif32/tools/sdk/esp32s3/include/bt/esp_ble_mesh/mesh_common/include -I/Users/michaelvvt/.platformio/packages/framework-arduinoespressif32/tools/sdk/esp32s3/include/bt/esp_ble_mesh/mesh_common/tinycrypt/include -I/Users/michaelvvt/.platformio/packages/framework-arduinoespressif32/tools/sdk/esp32s3/include/bt/esp_ble_mesh/mesh_core -I/Users/michaelvvt/.platformio/packages/framework-arduinoespressif32/tools/sdk/esp32s3/include/bt/esp_ble_mesh/mesh_core/include -I/Users/michaelvvt/.platformio/packages/framework-arduinoespressif32/tools/sdk/esp32s3/include/bt/esp_ble_mesh/mesh_core/storage -I/Users/michaelvvt/.platformio/packages/framework-arduinoespressif32/tools/sdk/esp32s3/include/bt/esp_ble_mesh/btc/include -I/Users/michaelvvt/.platformio/packages/framework-arduinoespressif32/tools/sdk/esp32s3/include/bt/esp_ble_mesh/mesh_models/common/include -I/Users/michaelvvt/.platformio/packages/framework-arduinoespressif32/tools/sdk/esp32s3/include/bt/esp_ble_mesh/mesh_models/client/include -I/Users/michaelvvt/.platformio/packages/framework-arduinoespressif32/tools/sdk/esp32s3/include/bt/esp_ble_mesh/mesh_models/server/include -I/Users/michaelvvt/.platformio/packages/framework-arduinoespressif32/tools/sdk/esp32s3/include/bt/esp_ble_mesh/api/core/include -I/Users/michaelvvt/.platformio/packages/framework-arduinoespressif32/tools/sdk/esp32s3/include/bt/esp_ble_mesh/api/models/include -I/Users/michaelvvt/.platformio/packages/framework-arduinoespressif32/tools/sdk/esp32s3/include/bt/esp_ble_mesh/api -I/Users/michaelvvt/.platformio/packages/framework-arduinoespressif32/tools/sdk/esp32s3/include/cbor/port/include -I/Users/michaelvvt/.platformio/packages/framework-arduinoespressif32/tools/sdk/esp32s3/include/unity/include -I/Users/michaelvvt/.platformio/packages/framework-arduinoespressif32/tools/sdk/esp32s3/include/unity/unity/src -I/Users/michaelvvt/.platformio/packages/framework-arduinoespressif32/tools/sdk/esp32s3/include/cmock/CMock/src -I/Users/michaelvvt/.platformio/packages/framework-arduinoespressif32/tools/sdk/esp32s3/include/coap/port/include -I/Users/michaelvvt/.platformio/packages/framework-arduinoespressif32/tools/sdk/esp32s3/include/coap/libcoap/include -I/Users/michaelvvt/.platformio/packages/framework-arduinoespressif32/tools/sdk/esp32s3/include/nghttp/port/include -I/Users/michaelvvt/.platformio/packages/framework-arduinoespressif32/tools/sdk/esp32s3/include/nghttp/nghttp2/lib/includes -I/Users/michaelvvt/.platformio/packages/framework-arduinoespressif32/tools/sdk/esp32s3/include/esp-tls -I/Users/michaelvvt/.platformio/packages/framework-arduinoespressif32/tools/sdk/esp32s3/include/esp-tls/esp-tls-crypto -I/Users/michaelvvt/.platformio/packages/framework-arduinoespressif32/tools/sdk/esp32s3/include/esp_adc_cal/include -I/Users/michaelvvt/.platformio/packages/framework-arduinoespressif32/tools/sdk/esp32s3/include/esp_hid/include -I/Users/michaelvvt/.platformio/packages/framework-arduinoespressif32/tools/sdk/esp32s3/include/tcp_transport/include -I/Users/michaelvvt/.platformio/packages/framework-arduinoespressif32/tools/sdk/esp32s3/include/esp_http_client/include -I/Users/michaelvvt/.platformio/packages/framework-arduinoespressif32/tools/sdk/esp32s3/include/esp_http_server/include -I/Users/michaelvvt/.platformio/packages/framework-arduinoespressif32/tools/sdk/esp32s3/include/esp_https_ota/include -I/Users/michaelvvt/.platformio/packages/framework-arduinoespressif32/tools/sdk/esp32s3/include/esp_https_server/include -I/Users/michaelvvt/.platformio/packages/framework-arduinoespressif32/tools/sdk/esp32s3/include/esp_lcd/include -I/Users/michaelvvt/.platformio/packages/framework-arduinoespressif32/tools/sdk/esp32s3/include/esp_lcd/interface -I/Users/michaelvvt/.platformio/packages/framework-arduinoespressif32/tools/sdk/esp32s3/include/protobuf-c/protobuf-c -I/Users/michaelvvt/.platformio/packages/framework-arduinoespressif32/tools/sdk/esp32s3/include/protocomm/include/common -I/Users/michaelvvt/.platformio/packages/framework-arduinoespressif32/tools/sdk/esp32s3/include/protocomm/include/security -I/Users/michaelvvt/.platformio/packages/framework-arduinoespressif32/tools/sdk/esp32s3/include/protocomm/include/transports -I/Users/michaelvvt/.platformio/packages/framework-arduinoespressif32/tools/sdk/esp32s3/include/mdns/include -I/Users/michaelvvt/.platformio/packages/framework-arduinoespressif32/tools/sdk/esp32s3/include/esp_local_ctrl/include -I/Users/michaelvvt/.platformio/packages/framework-arduinoespressif32/tools/sdk/esp32s3/include/sdmmc/include -I/Users/michaelvvt/.platformio/packages/framework-arduinoespressif32/tools/sdk/esp32s3/include/esp_serial_slave_link/include -I/Users/michaelvvt/.platformio/packages/framework-arduinoespressif32/tools/sdk/esp32s3/include/esp_websocket_client/include -I/Users/michaelvvt/.platformio/packages/framework-arduinoespressif32/tools/sdk/esp32s3/include/expat/expat/expat/lib -I/Users/michaelvvt/.platformio/packages/framework-arduinoespressif32/tools/sdk/esp32s3/include/expat/port/include -I/Users/michaelvvt/.platformio/packages/framework-arduinoespressif32/tools/sdk/esp32s3/include/wear_levelling/include -I/Users/michaelvvt/.platformio/packages/framework-arduinoespressif32/tools/sdk/esp32s3/include/fatfs/diskio -I/Users/michaelvvt/.platformio/packages/framework-arduinoespressif32/tools/sdk/esp32s3/include/fatfs/vfs -I/Users/michaelvvt/.platformio/packages/framework-arduinoespressif32/tools/sdk/esp32s3/include/fatfs/src -I/Users/michaelvvt/.platformio/packages/framework-arduinoespressif32/tools/sdk/esp32s3/include/freemodbus/freemodbus/common/include -I/Users/michaelvvt/.platformio/packages/framework-arduinoespressif32/tools/sdk/esp32s3/include/idf_test/include -I/Users/michaelvvt/.platformio/packages/framework-arduinoespressif32/tools/sdk/esp32s3/include/idf_test/include/esp32s3 -I/Users/michaelvvt/.platformio/packages/framework-arduinoespressif32/tools/sdk/esp32s3/include/jsmn/include -I/Users/michaelvvt/.platformio/packages/framework-arduinoespressif32/tools/sdk/esp32s3/include/json/cJSON -I/Users/michaelvvt/.platformio/packages/framework-arduinoespressif32/tools/sdk/esp32s3/include/libsodium/libsodium/src/libsodium/include -I/Users/michaelvvt/.platformio/packages/framework-arduinoespressif32/tools/sdk/esp32s3/include/libsodium/port_include -I/Users/michaelvvt/.platformio/packages/framework-arduinoespressif32/tools/sdk/esp32s3/include/mqtt/esp-mqtt/include -I/Users/michaelvvt/.platformio/packages/framework-arduinoespressif32/tools/sdk/esp32s3/include/openssl/include -I/Users/michaelvvt/.platformio/packages/framework-arduinoespressif32/tools/sdk/esp32s3/include/perfmon/include -I/Users/michaelvvt/.platformio/packages/framework-arduinoespressif32/tools/sdk/esp32s3/include/spiffs/include -I/Users/michaelvvt/.platformio/packages/framework-arduinoespressif32/tools/sdk/esp32s3/include/usb/include -I/Users/michaelvvt/.platformio/packages/framework-arduinoespressif32/tools/sdk/esp32s3/include/ulp/include -I/Users/michaelvvt/.platformio/packages/framework-arduinoespressif32/tools/sdk/esp32s3/include/wifi_provisioning/include -I/Users/michaelvvt/.platformio/packages/framework-arduinoespressif32/tools/sdk/esp32s3/include/rmaker_common/include -I/Users/michaelvvt/.platformio/packages/framework-arduinoespressif32/tools/sdk/esp32s3/include/esp_diagnostics/include -I/Users/michaelvvt/.platformio/packages/framework-arduinoespressif32/tools/sdk/esp32s3/include/rtc_store/include -I/Users/michaelvvt/.platformio/packages/framework-arduinoespressif32/tools/sdk/esp32s3/include/esp_insights/include -I/Users/michaelvvt/.platformio/packages/framework-arduinoespressif32/tools/sdk/esp32s3/include/json_parser/upstream/include -I/Users/michaelvvt/.platformio/packages/framework-arduinoespressif32/tools/sdk/esp32s3/include/json_parser/upstream -I/Users/michaelvvt/.platformio/packages/framework-arduinoespressif32/tools/sdk/esp32s3/include/json_generator/upstream -I/Users/michaelvvt/.platformio/packages/framework-arduinoespressif32/tools/sdk/esp32s3/include/esp_schedule/include -I/Users/michaelvvt/.platformio/packages/framework-arduinoespressif32/tools/sdk/esp32s3/include/espressif__esp_secure_cert_mgr/include -I/Users/michaelvvt/.platformio/packages/framework-arduinoespressif32/tools/sdk/esp32s3/include/esp_rainmaker/include -I/Users/michaelvvt/.platformio/packages/framework-arduinoespressif32/tools/sdk/esp32s3/include/gpio_button/button/include -I/Users/michaelvvt/.platformio/packages/framework-arduinoespressif32/tools/sdk/esp32s3/include/qrcode/include -I/Users/michaelvvt/.platformio/packages/framework-arduinoespressif32/tools/sdk/esp32s3/include/ws2812_led -I/Users/michaelvvt/.platformio/packages/framework-arduinoespressif32/tools/sdk/esp32s3/include/freertos/include/freertos -I/Users/michaelvvt/.platformio/packages/framework-arduinoespressif32/tools/sdk/esp32s3/include/arduino_tinyusb/tinyusb/src -I/Users/michaelvvt/.platformio/packages/framework-arduinoespressif32/tools/sdk/esp32s3/include/arduino_tinyusb/include -I/Users/michaelvvt/.platformio/packages/framework-arduinoespressif32/tools/sdk/esp32s3/include/esp_littlefs/include -I/Users/michaelvvt/.platformio/packages/framework-arduinoespressif32/tools/sdk/esp32s3/include/esp-dl/include -I/Users/michaelvvt/.platformio/packages/framework-arduinoespressif32/tools/sdk/esp32s3/include/esp-dl/include/tool -I/Users/michaelvvt/.platformio/packages/framework-arduinoespressif32/tools/sdk/esp32s3/include/esp-dl/include/typedef -I/Users/michaelvvt/.platformio/packages/framework-arduinoespressif32/tools/sdk/esp32s3/include/esp-dl/include/image -I/Users/michaelvvt/.platformio/packages/framework-arduinoespressif32/tools/sdk/esp32s3/include/esp-dl/include/math -I/Users/michaelvvt/.platformio/packages/framework-arduinoespressif32/tools/sdk/esp32s3/include/esp-dl/include/nn -I/Users/michaelvvt/.platformio/packages/framework-arduinoespressif32/tools/sdk/esp32s3/include/esp-dl/include/layer -I/Users/michaelvvt/.platformio/packages/framework-arduinoespressif32/tools/sdk/esp32s3/include/esp-dl/include/detect -I/Users/michaelvvt/.platformio/packages/framework-arduinoespressif32/tools/sdk/esp32s3/include/esp-dl/include/model_zoo -I/Users/michaelvvt/.platformio/packages/framework-arduinoespressif32/tools/sdk/esp32s3/include/esp32-camera/driver/include -I/Users/michaelvvt/.platformio/packages/framework-arduinoespressif32/tools/sdk/esp32s3/include/esp32-camera/conversions/include -I/Users/michaelvvt/.platformio/packages/framework-arduinoespressif32/tools/sdk/esp32s3/include/espressif__esp-dsp/modules/dotprod/include -I/Users/michaelvvt/.platformio/packages/framework-arduinoespressif32/tools/sdk/esp32s3/include/espressif__esp-dsp/modules/support/include -I/Users/michaelvvt/.platformio/packages/framework-arduinoespressif32/tools/sdk/esp32s3/include/espressif__esp-dsp/modules/support/mem/include -I/Users/michaelvvt/.platformio/packages/framework-arduinoespressif32/tools/sdk/esp32s3/include/espressif__esp-dsp/modules/windows/include -I/Users/michaelvvt/.platformio/packages/framework-arduinoespressif32/tools/sdk/esp32s3/include/espressif__esp-dsp/modules/windows/hann/include -I/Users/michaelvvt/.platformio/packages/framework-arduinoespressif32/tools/sdk/esp32s3/include/espressif__esp-dsp/modules/windows/blackman/include -I/Users/michaelvvt/.platformio/packages/framework-arduinoespressif32/tools/sdk/esp32s3/include/espressif__esp-dsp/modules/windows/blackman_harris/include -I/Users/michaelvvt/.platformio/packages/framework-arduinoespressif32/tools/sdk/esp32s3/include/espressif__esp-dsp/modules/windows/blackman_nuttall/include -I/Users/michaelvvt/.platformio/packages/framework-arduinoespressif32/tools/sdk/esp32s3/include/espressif__esp-dsp/modules/windows/nuttall/include -I/Users/michaelvvt/.platformio/packages/framework-arduinoespressif32/tools/sdk/esp32s3/include/espressif__esp-dsp/modules/windows/flat_top/include -I/Users/michaelvvt/.platformio/packages/framework-arduinoespressif32/tools/sdk/esp32s3/include/espressif__esp-dsp/modules/iir/include -I/Users/michaelvvt/.platformio/packages/framework-arduinoespressif32/tools/sdk/esp32s3/include/espressif__esp-dsp/modules/fir/include -I/Users/michaelvvt/.platformio/packages/framework-arduinoespressif32/tools/sdk/esp32s3/include/espressif__esp-dsp/modules/math/include -I/Users/michaelvvt/.platformio/packages/framework-arduinoespressif32/tools/sdk/esp32s3/include/espressif__esp-dsp/modules/math/add/include -I/Users/michaelvvt/.platformio/packages/framework-arduinoespressif32/tools/sdk/esp32s3/include/espressif__esp-dsp/modules/math/sub/include -I/Users/michaelvvt/.platformio/packages/framework-arduinoespressif32/tools/sdk/esp32s3/include/espressif__esp-dsp/modules/math/mul/include -I/Users/michaelvvt/.platformio/packages/framework-arduinoespressif32/tools/sdk/esp32s3/include/espressif__esp-dsp/modules/math/addc/include -I/Users/michaelvvt/.platformio/packages/framework-arduinoespressif32/tools/sdk/esp32s3/include/espressif__esp-dsp/modules/math/mulc/include -I/Users/michaelvvt/.platformio/packages/framework-arduinoespressif32/tools/sdk/esp32s3/include/espressif__esp-dsp/modules/math/sqrt/include -I/Users/michaelvvt/.platformio/packages/framework-arduinoespressif32/tools/sdk/esp32s3/include/espressif__esp-dsp/modules/matrix/mul/include -I/Users/michaelvvt/.platformio/packages/framework-arduinoespressif32/tools/sdk/esp32s3/include/espressif__esp-dsp/modules/matrix/add/include -I/Users/michaelvvt/.platformio/packages/framework-arduinoespressif32/tools/sdk/esp32s3/include/espressif__esp-dsp/modules/matrix/addc/include -I/Users/michaelvvt/.platformio/packages/framework-arduinoespressif32/tools/sdk/esp32s3/include/espressif__esp-dsp/modules/matrix/mulc/include -I/Users/michaelvvt/.platformio/packages/framework-arduinoespressif32/tools/sdk/esp32s3/include/espressif__esp-dsp/modules/matrix/sub/include -I/Users/michaelvvt/.platformio/packages/framework-arduinoespressif32/tools/sdk/esp32s3/include/espressif__esp-dsp/modules/matrix/include -I/Users/michaelvvt/.platformio/packages/framework-arduinoespressif32/tools/sdk/esp32s3/include/espressif__esp-dsp/modules/fft/include -I/Users/michaelvvt/.platformio/packages/framework-arduinoespressif32/tools/sdk/esp32s3/include/espressif__esp-dsp/modules/dct/include -I/Users/michaelvvt/.platformio/packages/framework-arduinoespressif32/tools/sdk/esp32s3/include/espressif__esp-dsp/modules/conv/include -I/Users/michaelvvt/.platformio/packages/framework-arduinoespressif32/tools/sdk/esp32s3/include/espressif__esp-dsp/modules/common/include -I/Users/michaelvvt/.platformio/packages/framework-arduinoespressif32/tools/sdk/esp32s3/include/espressif__esp-dsp/modules/matrix/mul/test/include -I/Users/michaelvvt/.platformio/packages/framework-arduinoespressif32/tools/sdk/esp32s3/include/espressif__esp-dsp/modules/kalman/ekf/include -I/Users/michaelvvt/.platformio/packages/framework-arduinoespressif32/tools/sdk/esp32s3/include/espressif__esp-dsp/modules/kalman/ekf_imu13states/include -I/Users/michaelvvt/.platformio/packages/framework-arduinoespressif32/tools/sdk/esp32s3/include/fb_gfx/include -I/Users/michaelvvt/.platformio/packages/framework-arduinoespressif32/tools/sdk/esp32s3/qio_opi/include -I/Users/michaelvvt/.platformio/packages/framework-arduinoespressif32/cores/esp32 -I/Users/michaelvvt/.platformio/packages/framework-arduinoespressif32/variants/esp32s3box src/main.cpp
xtensa-esp32s3-elf-gcc-ar rc .pio/build/esp32s3box/lib575/libHX711.a .pio/build/esp32s3box/lib575/HX711/HX711.cpp.o
xtensa-esp32s3-elf-g++ -o .pio/build/esp32s3box/lib7c7/WiFi/WiFi.cpp.o -c -std=gnu++11 -fexceptions -fno-rtti -Os -mlongcalls -ffunction-sections -fdata-sections -Wno-error=unused-function -Wno-error=unused-variable -Wno-error=deprecated-declarations -Wno-unused-parameter -Wno-sign-compare -ggdb -freorder-blocks -Wwrite-strings -fstack-protector -fstrict-volatile-bitfields -Wno-error=unused-but-set-variable -fno-jump-tables -fno-tree-switch-conversion -MMD -DPLATFORMIO=60118 -DBOARD_HAS_PSRAM -DARDUINO_ESP32_S3_BOX -DARDUINO_USB_MODE=1 -DARDUINO_USB_CDC_ON_BOOT=1 -DHAVE_CONFIG_H -DMBEDTLS_CONFIG_FILE=\"mbedtls/esp_config.h\" -DUNITY_INCLUDE_CONFIG_H -DWITH_POSIX -D_GNU_SOURCE -DIDF_VER=\"v4.4.7-dirty\" -DESP_PLATFORM -D_POSIX_READER_WRITER_LOCKS -DARDUINO_ARCH_ESP32 -DESP32 -DF_CPU=240000000L -DARDUINO=10812 -DARDUINO_VARIANT=\"esp32s3box\" "-DARDUINO_BOARD=\"Espressif ESP32-S3-Box\"" -DARDUINO_PARTITION_min_spiffs -I/Users/michaelvvt/.platformio/packages/framework-arduinoespressif32/libraries/WiFi/src -I/Users/michaelvvt/.platformio/packages/framework-arduinoespressif32/tools/sdk/esp32s3/include/newlib/platform_include -I/Users/michaelvvt/.platformio/packages/framework-arduinoespressif32/tools/sdk/esp32s3/include/freertos/include -I/Users/michaelvvt/.platformio/packages/framework-arduinoespressif32/tools/sdk/esp32s3/include/freertos/include/esp_additions/freertos -I/Users/michaelvvt/.platformio/packages/framework-arduinoespressif32/tools/sdk/esp32s3/include/freertos/port/xtensa/include -I/Users/michaelvvt/.platformio/packages/framework-arduinoespressif32/tools/sdk/esp32s3/include/freertos/include/esp_additions -I/Users/michaelvvt/.platformio/packages/framework-arduinoespressif32/tools/sdk/esp32s3/include/esp_hw_support/include -I/Users/michaelvvt/.platformio/packages/framework-arduinoespressif32/tools/sdk/esp32s3/include/esp_hw_support/include/soc -I/Users/michaelvvt/.platformio/packages/framework-arduinoespressif32/tools/sdk/esp32s3/include/esp_hw_support/include/soc/esp32s3 -I/Users/michaelvvt/.platformio/packages/framework-arduinoespressif32/tools/sdk/esp32s3/include/esp_hw_support/port/esp32s3 -I/Users/michaelvvt/.platformio/packages/framework-arduinoespressif32/tools/sdk/esp32s3/include/esp_hw_support/port/esp32s3/private_include -I/Users/michaelvvt/.platformio/packages/framework-arduinoespressif32/tools/sdk/esp32s3/include/heap/include -I/Users/michaelvvt/.platformio/packages/framework-arduinoespressif32/tools/sdk/esp32s3/include/log/include -I/Users/michaelvvt/.platformio/packages/framework-arduinoespressif32/tools/sdk/esp32s3/include/lwip/include/apps -I/Users/michaelvvt/.platformio/packages/framework-arduinoespressif32/tools/sdk/esp32s3/include/lwip/include/apps/sntp -I/Users/michaelvvt/.platformio/packages/framework-arduinoespressif32/tools/sdk/esp32s3/include/lwip/lwip/src/include -I/Users/michaelvvt/.platformio/packages/framework-arduinoespressif32/tools/sdk/esp32s3/include/lwip/port/esp32/include -I/Users/michaelvvt/.platformio/packages/framework-arduinoespressif32/tools/sdk/esp32s3/include/lwip/port/esp32/include/arch -I/Users/michaelvvt/.platformio/packages/framework-arduinoespressif32/tools/sdk/esp32s3/include/soc/include -I/Users/michaelvvt/.platformio/packages/framework-arduinoespressif32/tools/sdk/esp32s3/include/soc/esp32s3 -I/Users/michaelvvt/.platformio/packages/framework-arduinoespressif32/tools/sdk/esp32s3/include/soc/esp32s3/include -I/Users/michaelvvt/.platformio/packages/framework-arduinoespressif32/tools/sdk/esp32s3/include/hal/esp32s3/include -I/Users/michaelvvt/.platformio/packages/framework-arduinoespressif32/tools/sdk/esp32s3/include/hal/include -I/Users/michaelvvt/.platformio/packages/framework-arduinoespressif32/tools/sdk/esp32s3/include/hal/platform_port/include -I/Users/michaelvvt/.platformio/packages/framework-arduinoespressif32/tools/sdk/esp32s3/include/esp_rom/include -I/Users/michaelvvt/.platformio/packages/framework-arduinoespressif32/tools/sdk/esp32s3/include/esp_rom/include/esp32s3 -I/Users/michaelvvt/.platformio/packages/framework-arduinoespressif32/tools/sdk/esp32s3/include/esp_rom/esp32s3 -I/Users/michaelvvt/.platformio/packages/framework-arduinoespressif32/tools/sdk/esp32s3/include/esp_common/include -I/Users/michaelvvt/.platformio/packages/framework-arduinoespressif32/tools/sdk/esp32s3/include/esp_system/include -I/Users/michaelvvt/.platformio/packages/framework-arduinoespressif32/tools/sdk/esp32s3/include/esp_system/port/soc -I/Users/michaelvvt/.platformio/packages/framework-arduinoespressif32/tools/sdk/esp32s3/include/esp_system/port/public_compat -I/Users/michaelvvt/.platformio/packages/framework-arduinoespressif32/tools/sdk/esp32s3/include/xtensa/include -I/Users/michaelvvt/.platformio/packages/framework-arduinoespressif32/tools/sdk/esp32s3/include/xtensa/esp32s3/include -I/Users/michaelvvt/.platformio/packages/framework-arduinoespressif32/tools/sdk/esp32s3/include/driver/include -I/Users/michaelvvt/.platformio/packages/framework-arduinoespressif32/tools/sdk/esp32s3/include/driver/esp32s3/include -I/Users/michaelvvt/.platformio/packages/framework-arduinoespressif32/tools/sdk/esp32s3/include/esp_pm/include -I/Users/michaelvvt/.platformio/packages/framework-arduinoespressif32/tools/sdk/esp32s3/include/esp_ringbuf/include -I/Users/michaelvvt/.platformio/packages/framework-arduinoespressif32/tools/sdk/esp32s3/include/efuse/include -I/Users/michaelvvt/.platformio/packages/framework-arduinoespressif32/tools/sdk/esp32s3/include/efuse/esp32s3/include -I/Users/michaelvvt/.platformio/packages/framework-arduinoespressif32/tools/sdk/esp32s3/include/vfs/include -I/Users/michaelvvt/.platformio/packages/framework-arduinoespressif32/tools/sdk/esp32s3/include/esp_wifi/include -I/Users/michaelvvt/.platformio/packages/framework-arduinoespressif32/tools/sdk/esp32s3/include/esp_event/include -I/Users/michaelvvt/.platformio/packages/framework-arduinoespressif32/tools/sdk/esp32s3/include/esp_netif/include -I/Users/michaelvvt/.platformio/packages/framework-arduinoespressif32/tools/sdk/esp32s3/include/esp_eth/include -I/Users/michaelvvt/.platformio/packages/framework-arduinoespressif32/tools/sdk/esp32s3/include/tcpip_adapter/include -I/Users/michaelvvt/.platformio/packages/framework-arduinoespressif32/tools/sdk/esp32s3/include/esp_phy/include -I/Users/michaelvvt/.platformio/packages/framework-arduinoespressif32/tools/sdk/esp32s3/include/esp_phy/esp32s3/include -I/Users/michaelvvt/.platformio/packages/framework-arduinoespressif32/tools/sdk/esp32s3/include/esp_ipc/include -I/Users/michaelvvt/.platformio/packages/framework-arduinoespressif32/tools/sdk/esp32s3/include/app_trace/include -I/Users/michaelvvt/.platformio/packages/framework-arduinoespressif32/tools/sdk/esp32s3/include/esp_timer/include -I/Users/michaelvvt/.platformio/packages/framework-arduinoespressif32/tools/sdk/esp32s3/include/mbedtls/port/include -I/Users/michaelvvt/.platformio/packages/framework-arduinoespressif32/tools/sdk/esp32s3/include/mbedtls/mbedtls/include -I/Users/michaelvvt/.platformio/packages/framework-arduinoespressif32/tools/sdk/esp32s3/include/mbedtls/esp_crt_bundle/include -I/Users/michaelvvt/.platformio/packages/framework-arduinoespressif32/tools/sdk/esp32s3/include/app_update/include -I/Users/michaelvvt/.platformio/packages/framework-arduinoespressif32/tools/sdk/esp32s3/include/spi_flash/include -I/Users/michaelvvt/.platformio/packages/framework-arduinoespressif32/tools/sdk/esp32s3/include/bootloader_support/include -I/Users/michaelvvt/.platformio/packages/framework-arduinoespressif32/tools/sdk/esp32s3/include/nvs_flash/include -I/Users/michaelvvt/.platformio/packages/framework-arduinoespressif32/tools/sdk/esp32s3/include/pthread/include -I/Users/michaelvvt/.platformio/packages/framework-arduinoespressif32/tools/sdk/esp32s3/include/esp_gdbstub/include -I/Users/michaelvvt/.platformio/packages/framework-arduinoespressif32/tools/sdk/esp32s3/include/esp_gdbstub/xtensa -I/Users/michaelvvt/.platformio/packages/framework-arduinoespressif32/tools/sdk/esp32s3/include/esp_gdbstub/esp32s3 -I/Users/michaelvvt/.platformio/packages/framework-arduinoespressif32/tools/sdk/esp32s3/include/espcoredump/include -I/Users/michaelvvt/.platformio/packages/framework-arduinoespressif32/tools/sdk/esp32s3/include/espcoredump/include/port/xtensa -I/Users/michaelvvt/.platformio/packages/framework-arduinoespressif32/tools/sdk/esp32s3/include/wpa_supplicant/include -I/Users/michaelvvt/.platformio/packages/framework-arduinoespressif32/tools/sdk/esp32s3/include/wpa_supplicant/port/include -I/Users/michaelvvt/.platformio/packages/framework-arduinoespressif32/tools/sdk/esp32s3/include/wpa_supplicant/esp_supplicant/include -I/Users/michaelvvt/.platformio/packages/framework-arduinoespressif32/tools/sdk/esp32s3/include/ieee802154/include -I/Users/michaelvvt/.platformio/packages/framework-arduinoespressif32/tools/sdk/esp32s3/include/console -I/Users/michaelvvt/.platformio/packages/framework-arduinoespressif32/tools/sdk/esp32s3/include/asio/asio/asio/include -I/Users/michaelvvt/.platformio/packages/framework-arduinoespressif32/tools/sdk/esp32s3/include/asio/port/include -I/Users/michaelvvt/.platformio/packages/framework-arduinoespressif32/tools/sdk/esp32s3/include/bt/common/osi/include -I/Users/michaelvvt/.platformio/packages/framework-arduinoespressif32/tools/sdk/esp32s3/include/bt/include/esp32c3/include -I/Users/michaelvvt/.platformio/packages/framework-arduinoespressif32/tools/sdk/esp32s3/include/bt/common/api/include/api -I/Users/michaelvvt/.platformio/packages/framework-arduinoespressif32/tools/sdk/esp32s3/include/bt/common/btc/profile/esp/blufi/include -I/Users/michaelvvt/.platformio/packages/framework-arduinoespressif32/tools/sdk/esp32s3/include/bt/common/btc/profile/esp/include -I/Users/michaelvvt/.platformio/packages/framework-arduinoespressif32/tools/sdk/esp32s3/include/bt/host/bluedroid/api/include/api -I/Users/michaelvvt/.platformio/packages/framework-arduinoespressif32/tools/sdk/esp32s3/include/bt/esp_ble_mesh/mesh_common/include -I/Users/michaelvvt/.platformio/packages/framework-arduinoespressif32/tools/sdk/esp32s3/include/bt/esp_ble_mesh/mesh_common/tinycrypt/include -I/Users/michaelvvt/.platformio/packages/framework-arduinoespressif32/tools/sdk/esp32s3/include/bt/esp_ble_mesh/mesh_core -I/Users/michaelvvt/.platformio/packages/framework-arduinoespressif32/tools/sdk/esp32s3/include/bt/esp_ble_mesh/mesh_core/include -I/Users/michaelvvt/.platformio/packages/framework-arduinoespressif32/tools/sdk/esp32s3/include/bt/esp_ble_mesh/mesh_core/storage -I/Users/michaelvvt/.platformio/packages/framework-arduinoespressif32/tools/sdk/esp32s3/include/bt/esp_ble_mesh/btc/include -I/Users/michaelvvt/.platformio/packages/framework-arduinoespressif32/tools/sdk/esp32s3/include/bt/esp_ble_mesh/mesh_models/common/include -I/Users/michaelvvt/.platformio/packages/framework-arduinoespressif32/tools/sdk/esp32s3/include/bt/esp_ble_mesh/mesh_models/client/include -I/Users/michaelvvt/.platformio/packages/framework-arduinoespressif32/tools/sdk/esp32s3/include/bt/esp_ble_mesh/mesh_models/server/include -I/Users/michaelvvt/.platformio/packages/framework-arduinoespressif32/tools/sdk/esp32s3/include/bt/esp_ble_mesh/api/core/include -I/Users/michaelvvt/.platformio/packages/framework-arduinoespressif32/tools/sdk/esp32s3/include/bt/esp_ble_mesh/api/models/include -I/Users/michaelvvt/.platformio/packages/framework-arduinoespressif32/tools/sdk/esp32s3/include/bt/esp_ble_mesh/api -I/Users/michaelvvt/.platformio/packages/framework-arduinoespressif32/tools/sdk/esp32s3/include/cbor/port/include -I/Users/michaelvvt/.platformio/packages/framework-arduinoespressif32/tools/sdk/esp32s3/include/unity/include -I/Users/michaelvvt/.platformio/packages/framework-arduinoespressif32/tools/sdk/esp32s3/include/unity/unity/src -I/Users/michaelvvt/.platformio/packages/framework-arduinoespressif32/tools/sdk/esp32s3/include/cmock/CMock/src -I/Users/michaelvvt/.platformio/packages/framework-arduinoespressif32/tools/sdk/esp32s3/include/coap/port/include -I/Users/michaelvvt/.platformio/packages/framework-arduinoespressif32/tools/sdk/esp32s3/include/coap/libcoap/include -I/Users/michaelvvt/.platformio/packages/framework-arduinoespressif32/tools/sdk/esp32s3/include/nghttp/port/include -I/Users/michaelvvt/.platformio/packages/framework-arduinoespressif32/tools/sdk/esp32s3/include/nghttp/nghttp2/lib/includes -I/Users/michaelvvt/.platformio/packages/framework-arduinoespressif32/tools/sdk/esp32s3/include/esp-tls -I/Users/michaelvvt/.platformio/packages/framework-arduinoespressif32/tools/sdk/esp32s3/include/esp-tls/esp-tls-crypto -I/Users/michaelvvt/.platformio/packages/framework-arduinoespressif32/tools/sdk/esp32s3/include/esp_adc_cal/include -I/Users/michaelvvt/.platformio/packages/framework-arduinoespressif32/tools/sdk/esp32s3/include/esp_hid/include -I/Users/michaelvvt/.platformio/packages/framework-arduinoespressif32/tools/sdk/esp32s3/include/tcp_transport/include -I/Users/michaelvvt/.platformio/packages/framework-arduinoespressif32/tools/sdk/esp32s3/include/esp_http_client/include -I/Users/michaelvvt/.platformio/packages/framework-arduinoespressif32/tools/sdk/esp32s3/include/esp_http_server/include -I/Users/michaelvvt/.platformio/packages/framework-arduinoespressif32/tools/sdk/esp32s3/include/esp_https_ota/include -I/Users/michaelvvt/.platformio/packages/framework-arduinoespressif32/tools/sdk/esp32s3/include/esp_https_server/include -I/Users/michaelvvt/.platformio/packages/framework-arduinoespressif32/tools/sdk/esp32s3/include/esp_lcd/include -I/Users/michaelvvt/.platformio/packages/framework-arduinoespressif32/tools/sdk/esp32s3/include/esp_lcd/interface -I/Users/michaelvvt/.platformio/packages/framework-arduinoespressif32/tools/sdk/esp32s3/include/protobuf-c/protobuf-c -I/Users/michaelvvt/.platformio/packages/framework-arduinoespressif32/tools/sdk/esp32s3/include/protocomm/include/common -I/Users/michaelvvt/.platformio/packages/framework-arduinoespressif32/tools/sdk/esp32s3/include/protocomm/include/security -I/Users/michaelvvt/.platformio/packages/framework-arduinoespressif32/tools/sdk/esp32s3/include/protocomm/include/transports -I/Users/michaelvvt/.platformio/packages/framework-arduinoespressif32/tools/sdk/esp32s3/include/mdns/include -I/Users/michaelvvt/.platformio/packages/framework-arduinoespressif32/tools/sdk/esp32s3/include/esp_local_ctrl/include -I/Users/michaelvvt/.platformio/packages/framework-arduinoespressif32/tools/sdk/esp32s3/include/sdmmc/include -I/Users/michaelvvt/.platformio/packages/framework-arduinoespressif32/tools/sdk/esp32s3/include/esp_serial_slave_link/include -I/Users/michaelvvt/.platformio/packages/framework-arduinoespressif32/tools/sdk/esp32s3/include/esp_websocket_client/include -I/Users/michaelvvt/.platformio/packages/framework-arduinoespressif32/tools/sdk/esp32s3/include/expat/expat/expat/lib -I/Users/michaelvvt/.platformio/packages/framework-arduinoespressif32/tools/sdk/esp32s3/include/expat/port/include -I/Users/michaelvvt/.platformio/packages/framework-arduinoespressif32/tools/sdk/esp32s3/include/wear_levelling/include -I/Users/michaelvvt/.platformio/packages/framework-arduinoespressif32/tools/sdk/esp32s3/include/fatfs/diskio -I/Users/michaelvvt/.platformio/packages/framework-arduinoespressif32/tools/sdk/esp32s3/include/fatfs/vfs -I/Users/michaelvvt/.platformio/packages/framework-arduinoespressif32/tools/sdk/esp32s3/include/fatfs/src -I/Users/michaelvvt/.platformio/packages/framework-arduinoespressif32/tools/sdk/esp32s3/include/freemodbus/freemodbus/common/include -I/Users/michaelvvt/.platformio/packages/framework-arduinoespressif32/tools/sdk/esp32s3/include/idf_test/include -I/Users/michaelvvt/.platformio/packages/framework-arduinoespressif32/tools/sdk/esp32s3/include/idf_test/include/esp32s3 -I/Users/michaelvvt/.platformio/packages/framework-arduinoespressif32/tools/sdk/esp32s3/include/jsmn/include -I/Users/michaelvvt/.platformio/packages/framework-arduinoespressif32/tools/sdk/esp32s3/include/json/cJSON -I/Users/michaelvvt/.platformio/packages/framework-arduinoespressif32/tools/sdk/esp32s3/include/libsodium/libsodium/src/libsodium/include -I/Users/michaelvvt/.platformio/packages/framework-arduinoespressif32/tools/sdk/esp32s3/include/libsodium/port_include -I/Users/michaelvvt/.platformio/packages/framework-arduinoespressif32/tools/sdk/esp32s3/include/mqtt/esp-mqtt/include -I/Users/michaelvvt/.platformio/packages/framework-arduinoespressif32/tools/sdk/esp32s3/include/openssl/include -I/Users/michaelvvt/.platformio/packages/framework-arduinoespressif32/tools/sdk/esp32s3/include/perfmon/include -I/Users/michaelvvt/.platformio/packages/framework-arduinoespressif32/tools/sdk/esp32s3/include/spiffs/include -I/Users/michaelvvt/.platformio/packages/framework-arduinoespressif32/tools/sdk/esp32s3/include/usb/include -I/Users/michaelvvt/.platformio/packages/framework-arduinoespressif32/tools/sdk/esp32s3/include/ulp/include -I/Users/michaelvvt/.platformio/packages/framework-arduinoespressif32/tools/sdk/esp32s3/include/wifi_provisioning/include -I/Users/michaelvvt/.platformio/packages/framework-arduinoespressif32/tools/sdk/esp32s3/include/rmaker_common/include -I/Users/michaelvvt/.platformio/packages/framework-arduinoespressif32/tools/sdk/esp32s3/include/esp_diagnostics/include -I/Users/michaelvvt/.platformio/packages/framework-arduinoespressif32/tools/sdk/esp32s3/include/rtc_store/include -I/Users/michaelvvt/.platformio/packages/framework-arduinoespressif32/tools/sdk/esp32s3/include/esp_insights/include -I/Users/michaelvvt/.platformio/packages/framework-arduinoespressif32/tools/sdk/esp32s3/include/json_parser/upstream/include -I/Users/michaelvvt/.platformio/packages/framework-arduinoespressif32/tools/sdk/esp32s3/include/json_parser/upstream -I/Users/michaelvvt/.platformio/packages/framework-arduinoespressif32/tools/sdk/esp32s3/include/json_generator/upstream -I/Users/michaelvvt/.platformio/packages/framework-arduinoespressif32/tools/sdk/esp32s3/include/esp_schedule/include -I/Users/michaelvvt/.platformio/packages/framework-arduinoespressif32/tools/sdk/esp32s3/include/espressif__esp_secure_cert_mgr/include -I/Users/michaelvvt/.platformio/packages/framework-arduinoespressif32/tools/sdk/esp32s3/include/esp_rainmaker/include -I/Users/michaelvvt/.platformio/packages/framework-arduinoespressif32/tools/sdk/esp32s3/include/gpio_button/button/include -I/Users/michaelvvt/.platformio/packages/framework-arduinoespressif32/tools/sdk/esp32s3/include/qrcode/include -I/Users/michaelvvt/.platformio/packages/framework-arduinoespressif32/tools/sdk/esp32s3/include/ws2812_led -I/Users/michaelvvt/.platformio/packages/framework-arduinoespressif32/tools/sdk/esp32s3/include/freertos/include/freertos -I/Users/michaelvvt/.platformio/packages/framework-arduinoespressif32/tools/sdk/esp32s3/include/arduino_tinyusb/tinyusb/src -I/Users/michaelvvt/.platformio/packages/framework-arduinoespressif32/tools/sdk/esp32s3/include/arduino_tinyusb/include -I/Users/michaelvvt/.platformio/packages/framework-arduinoespressif32/tools/sdk/esp32s3/include/esp_littlefs/include -I/Users/michaelvvt/.platformio/packages/framework-arduinoespressif32/tools/sdk/esp32s3/include/esp-dl/include -I/Users/michaelvvt/.platformio/packages/framework-arduinoespressif32/tools/sdk/esp32s3/include/esp-dl/include/tool -I/Users/michaelvvt/.platformio/packages/framework-arduinoespressif32/tools/sdk/esp32s3/include/esp-dl/include/typedef -I/Users/michaelvvt/.platformio/packages/framework-arduinoespressif32/tools/sdk/esp32s3/include/esp-dl/include/image -I/Users/michaelvvt/.platformio/packages/framework-arduinoespressif32/tools/sdk/esp32s3/include/esp-dl/include/math -I/Users/michaelvvt/.platformio/packages/framework-arduinoespressif32/tools/sdk/esp32s3/include/esp-dl/include/nn -I/Users/michaelvvt/.platformio/packages/framework-arduinoespressif32/tools/sdk/esp32s3/include/esp-dl/include/layer -I/Users/michaelvvt/.platformio/packages/framework-arduinoespressif32/tools/sdk/esp32s3/include/esp-dl/include/detect -I/Users/michaelvvt/.platformio/packages/framework-arduinoespressif32/tools/sdk/esp32s3/include/esp-dl/include/model_zoo -I/Users/michaelvvt/.platformio/packages/framework-arduinoespressif32/tools/sdk/esp32s3/include/esp32-camera/driver/include -I/Users/michaelvvt/.platformio/packages/framework-arduinoespressif32/tools/sdk/esp32s3/include/esp32-camera/conversions/include -I/Users/michaelvvt/.platformio/packages/framework-arduinoespressif32/tools/sdk/esp32s3/include/espressif__esp-dsp/modules/dotprod/include -I/Users/michaelvvt/.platformio/packages/framework-arduinoespressif32/tools/sdk/esp32s3/include/espressif__esp-dsp/modules/support/include -I/Users/michaelvvt/.platformio/packages/framework-arduinoespressif32/tools/sdk/esp32s3/include/espressif__esp-dsp/modules/support/mem/include -I/Users/michaelvvt/.platformio/packages/framework-arduinoespressif32/tools/sdk/esp32s3/include/espressif__esp-dsp/modules/windows/include -I/Users/michaelvvt/.platformio/packages/framework-arduinoespressif32/tools/sdk/esp32s3/include/espressif__esp-dsp/modules/windows/hann/include -I/Users/michaelvvt/.platformio/packages/framework-arduinoespressif32/tools/sdk/esp32s3/include/espressif__esp-dsp/modules/windows/blackman/include -I/Users/michaelvvt/.platformio/packages/framework-arduinoespressif32/tools/sdk/esp32s3/include/espressif__esp-dsp/modules/windows/blackman_harris/include -I/Users/michaelvvt/.platformio/packages/framework-arduinoespressif32/tools/sdk/esp32s3/include/espressif__esp-dsp/modules/windows/blackman_nuttall/include -I/Users/michaelvvt/.platformio/packages/framework-arduinoespressif32/tools/sdk/esp32s3/include/espressif__esp-dsp/modules/windows/nuttall/include -I/Users/michaelvvt/.platformio/packages/framework-arduinoespressif32/tools/sdk/esp32s3/include/espressif__esp-dsp/modules/windows/flat_top/include -I/Users/michaelvvt/.platformio/packages/framework-arduinoespressif32/tools/sdk/esp32s3/include/espressif__esp-dsp/modules/iir/include -I/Users/michaelvvt/.platformio/packages/framework-arduinoespressif32/tools/sdk/esp32s3/include/espressif__esp-dsp/modules/fir/include -I/Users/michaelvvt/.platformio/packages/framework-arduinoespressif32/tools/sdk/esp32s3/include/espressif__esp-dsp/modules/math/include -I/Users/michaelvvt/.platformio/packages/framework-arduinoespressif32/tools/sdk/esp32s3/include/espressif__esp-dsp/modules/math/add/include -I/Users/michaelvvt/.platformio/packages/framework-arduinoespressif32/tools/sdk/esp32s3/include/espressif__esp-dsp/modules/math/sub/include -I/Users/michaelvvt/.platformio/packages/framework-arduinoespressif32/tools/sdk/esp32s3/include/espressif__esp-dsp/modules/math/mul/include -I/Users/michaelvvt/.platformio/packages/framework-arduinoespressif32/tools/sdk/esp32s3/include/espressif__esp-dsp/modules/math/addc/include -I/Users/michaelvvt/.platformio/packages/framework-arduinoespressif32/tools/sdk/esp32s3/include/espressif__esp-dsp/modules/math/mulc/include -I/Users/michaelvvt/.platformio/packages/framework-arduinoespressif32/tools/sdk/esp32s3/include/espressif__esp-dsp/modules/math/sqrt/include -I/Users/michaelvvt/.platformio/packages/framework-arduinoespressif32/tools/sdk/esp32s3/include/espressif__esp-dsp/modules/matrix/mul/include -I/Users/michaelvvt/.platformio/packages/framework-arduinoespressif32/tools/sdk/esp32s3/include/espressif__esp-dsp/modules/matrix/add/include -I/Users/michaelvvt/.platformio/packages/framework-arduinoespressif32/tools/sdk/esp32s3/include/espressif__esp-dsp/modules/matrix/addc/include -I/Users/michaelvvt/.platformio/packages/framework-arduinoespressif32/tools/sdk/esp32s3/include/espressif__esp-dsp/modules/matrix/mulc/include -I/Users/michaelvvt/.platformio/packages/framework-arduinoespressif32/tools/sdk/esp32s3/include/espressif__esp-dsp/modules/matrix/sub/include -I/Users/michaelvvt/.platformio/packages/framework-arduinoespressif32/tools/sdk/esp32s3/include/espressif__esp-dsp/modules/matrix/include -I/Users/michaelvvt/.platformio/packages/framework-arduinoespressif32/tools/sdk/esp32s3/include/espressif__esp-dsp/modules/fft/include -I/Users/michaelvvt/.platformio/packages/framework-arduinoespressif32/tools/sdk/esp32s3/include/espressif__esp-dsp/modules/dct/include -I/Users/michaelvvt/.platformio/packages/framework-arduinoespressif32/tools/sdk/esp32s3/include/espressif__esp-dsp/modules/conv/include -I/Users/michaelvvt/.platformio/packages/framework-arduinoespressif32/tools/sdk/esp32s3/include/espressif__esp-dsp/modules/common/include -I/Users/michaelvvt/.platformio/packages/framework-arduinoespressif32/tools/sdk/esp32s3/include/espressif__esp-dsp/modules/matrix/mul/test/include -I/Users/michaelvvt/.platformio/packages/framework-arduinoespressif32/tools/sdk/esp32s3/include/espressif__esp-dsp/modules/kalman/ekf/include -I/Users/michaelvvt/.platformio/packages/framework-arduinoespressif32/tools/sdk/esp32s3/include/espressif__esp-dsp/modules/kalman/ekf_imu13states/include -I/Users/michaelvvt/.platformio/packages/framework-arduinoespressif32/tools/sdk/esp32s3/include/fb_gfx/include -I/Users/michaelvvt/.platformio/packages/framework-arduinoespressif32/tools/sdk/esp32s3/qio_opi/include -I/Users/michaelvvt/.platformio/packages/framework-arduinoespressif32/cores/esp32 -I/Users/michaelvvt/.platformio/packages/framework-arduinoespressif32/variants/esp32s3box /Users/michaelvvt/.platformio/packages/framework-arduinoespressif32/libraries/WiFi/src/WiFi.cpp
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

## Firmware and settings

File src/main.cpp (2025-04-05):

#include "arduino.h"
#include <battery.h>
#include <scale.h>
#include <filter.h>
#include "jd9613.h"
#include "lvgl.h"
#include "pin_config.h"
#include "SPI.h"
#include "time.h"
#include "sntp.h"
#define TOUCH_MODULES_CST_SELF
#include "TouchLib.h"
#include "Wire.h"
#include "wifiManager.h"
#include <PrettyOTA.h>
#include "ble_service.h"

#ifndef BOARD_HAS_PSRAM
#error "Please turn on PSRAM option to OPI PSRAM"
#endif

WiFiManager wifiManager;
String header;

AsyncWebServer  server(80); // Server on port 80 (HTTP)
PrettyOTA       OTAUpdates;

static const uint16_t screenWidth = 294 * 2; // screenWidth = 294 * 2;
static const uint16_t screenHeight = 126;
static const size_t lv_buffer_size = screenWidth * screenHeight * sizeof(lv_color_t);
static lv_disp_draw_buf_t draw_buf;
static lv_color_t *buf = NULL;
lv_obj_t *label_weight = NULL;
lv_obj_t *label_timer = NULL; // New label for timer

// Timer variables
static int timer = 0; // Initialize timer to 0
static bool timer_running = false; // Timer running state
static unsigned long last_update = 0; // Last update time

// For inactivity and deep sleep management
static unsigned long last_activity_time = 0; // Last activity time
static float lastWeight = 0; // Last weight value

static EventGroupHandle_t touch_eg;
#define GET_TOUCH_INT _BV(1)

extern uint8_t espressiscale_left_map[];
extern uint8_t espressiscale_right_map[];

TouchLib touch(Wire, PIN_IIC_SDA, PIN_IIC_SCL, CTS820_SLAVE_ADDRESS);

void my_print(const char *buf)
{
  Serial.printf(buf);
  Serial.flush();
}

inline void my_disp_flush(lv_disp_drv_t *disp, const lv_area_t *area, lv_color_t *color_p)
{
  // uint32_t w = (area->x2 - area->x1 + 1);
  uint32_t h = (area->y2 - area->y1 + 1);

  int _w1 = 294 - area->x1;
  int _w2 = area->x2 - 294 + 1;

  if (_w1 > 0)
  {
    TFT_CS_0_L;
    lcd_PushColors_SoftRotation(area->x1,
                  area->y1,
                  _w1,
                  h,
                  (uint16_t *)&color_p->full,
                  2); // Horizontal display
    TFT_CS_0_H;
  }
  if (_w2 > 0)
  {
    TFT_CS_1_L;
    lcd_PushColors_SoftRotation(0,
                  area->y1,
                  _w2,
                  h,
                  (uint16_t *)&color_p->full,
                  1); // Horizontal display
    TFT_CS_1_H;
  }

  lv_disp_flush_ready(disp);
}

static void lv_touchpad_read(lv_indev_drv_t *indev_driver, lv_indev_data_t *data)
{
  if (touch.read())
  {
    TP_Point t = touch.getPoint(0);
    int16_t x = 126 - t.x;
    int16_t y = x;
    x = t.y;
    data->point.x = x;
    t.x = x;
    data->point.y = y;
    t.y = y;

    /* Adjust black shadow areas. */
    if (t.x > 326)
      data->point.x = t.x - 32;

    if (t.x > 294 && t.x < 326)
      data->state = LV_INDEV_STATE_REL;
    else
      data->state = LV_INDEV_STATE_PR;
  }
  else
  {
    data->state = LV_INDEV_STATE_REL;
  }
}

void startWifi(void * parameter){
  wifiManager.setConnectRetries(10);
  wifiManager.autoConnect("EspressiScale");

  Serial.print("IP Address: ");
  Serial.println(WiFi.localIP());

  OTAUpdates.Begin(&server);
  server.begin();
  OTAUpdates.OverwriteAppVersion("1.0.0");

  vTaskDelete(NULL);
}

// Timer control functions for BLE
void startTimer() {
  timer_running = true;
  last_activity_time = millis(); // Reset the activity timer
  Serial.println("Timer started via BLE");
}

void stopTimer() {
  timer_running = false;
  last_activity_time = millis(); // Reset the activity timer
  Serial.println("Timer stopped via BLE");
}

void resetTimer() {
  timer = 0;
  timer_running = false;
  updateBLETimer(timer);
  last_activity_time = millis(); // Reset the activity timer
  Serial.println("Timer reset via BLE");
}

void setup()
{
  touch_eg = xEventGroupCreate();

  esp_sleep_enable_ext0_wakeup(GPIO_NUM_12, 0); // Touch interrupt is connected to GPIO 12

  Serial.begin(921600);
  Serial.println("HX711 with median filter and exponential smoothing");
  jd9613_init();
  TFT_CS_0_L;
  lcd_PushColors(0, 0, 294, 126, (uint16_t *)espressiscale_right_map, 1);
  TFT_CS_0_H;
  TFT_CS_1_L;
  lcd_PushColors(0, 0, 294, 126, (uint16_t *)espressiscale_left_map, 3);
  TFT_CS_1_H;
  delay(3000);

  lv_init();

  buf = (lv_color_t *)ps_malloc(lv_buffer_size);

  assert(buf);

  lv_disp_draw_buf_init(&draw_buf, buf, NULL, screenWidth * screenHeight);

  /*Initialize the display*/
  static lv_disp_drv_t disp_drv;
  lv_disp_drv_init(&disp_drv);

  /*Set the resolution of the display*/
  disp_drv.hor_res = screenWidth;
  disp_drv.ver_res = screenHeight;
  disp_drv.flush_cb = my_disp_flush;
  disp_drv.draw_buf = &draw_buf;
  disp_drv.full_refresh = 1;

  lv_disp_drv_register(&disp_drv);

  Wire.begin(PIN_IIC_SDA, PIN_IIC_SCL);
  touch.init();
  static lv_indev_drv_t indev_drv;
  lv_indev_drv_init(&indev_drv);
  indev_drv.type = LV_INDEV_TYPE_POINTER;
  indev_drv.read_cb = lv_touchpad_read;
  lv_indev_drv_register(&indev_drv);

  setupScale();
  setupBattery();
  setupBLE(); // Initialize BLE service

  // Clear the display after showing the logo
  lv_obj_clean(lv_scr_act());

  // Set the background color to black
  lv_obj_set_style_bg_color(lv_scr_act(), lv_color_black(), LV_PART_MAIN);

  // Create a label to display the weight
  label_weight = lv_label_create(lv_scr_act());
  lv_obj_set_style_text_font(label_weight, &lv_font_montserrat_48, LV_PART_MAIN);
  lv_obj_align(label_weight, LV_ALIGN_RIGHT_MID, -10, 0);

  // Create a label to display the timer
  label_timer = lv_label_create(lv_scr_act());
  lv_obj_set_style_text_font(label_timer, &lv_font_montserrat_48, LV_PART_MAIN);
  lv_obj_align(label_timer, LV_ALIGN_LEFT_MID, 10, 0); // Align to the left
  
  // Initialize the last activity time
  last_activity_time = millis();
  
  xTaskCreatePinnedToCore(
    startWifi, // Function to run on this task
    "startWifi", // Task name
    10000, // Stack size
    NULL, // Task parameter
    1, // Task priority
    NULL, // Task handle
    0 // Task core
  );
}

void loop()
{
  // Read filtered weight
  float currentWeight = medianFilter();
  
  // Update BLE with current weight
  updateBLEWeight(currentWeight);

  // Update the label with the current weight
  char weight_str[16];
  snprintf(weight_str, sizeof(weight_str), "%.1f g", currentWeight);
  lv_label_set_text(label_weight, weight_str);

  if (touch.read())
  {
    // Any touch interaction should reset the activity timer
    last_activity_time = millis();
    
    TP_Point t = touch.getPoint(0);
    int16_t x = t.y; // Adjusted to match the screen orientation

    if (x > screenWidth / 2)
    {
      timer_running = !timer_running; // Toggle timer state
      if (timer_running) {
        Serial.println("Timer started via touch");
      } else {
        Serial.println("Timer stopped via touch");
      }
      delay(1000); // Debounce delay
    }
    else
    {
      timer_running = false; // Stop the timer
      timer = 0; // Reset timer
      updateBLETimer(timer); // Update BLE with reset timer
      xTaskCreate( // To prevent halting the loop
        [] (void * parameter) {
          tareScale(); // Tare the scale
          vTaskDelete(NULL); // Delete the task once done
        },
        "TareTask", // Task name
        10000, // Stack size
        NULL, // Task parameter
        1, // Task priority
        NULL // Task handle
      );
      Serial.println("Tared and timer reset via touch");
    }
  }

  if (timer_running)
  {
    unsigned long current_time = millis();
    if (current_time - last_update >= 1000) // Update every second
    {
      timer++;
      last_update = current_time;
      
      // Update BLE with current timer
      updateBLETimer(timer);
    }
  }

  // Display the timer
  char timer_str[16];
  snprintf(timer_str, sizeof(timer_str), "%d s", timer);
  lv_label_set_text(label_timer, timer_str);
  
  // Check if the weight has changed significantly (indicating activity)
  if (abs(currentWeight - lastWeight) >= 1.0) {
    last_activity_time = millis(); // Reset the activity timer
  }
  
  // Check for inactivity
  if (!timer_running && millis() - last_activity_time >= 300000) // 5 minutes
  {
    Serial.println("Entering deep sleep due to inactivity...");
    // Flush the screen to black before going to deep sleep
    lv_obj_clean(lv_scr_act());
    lv_obj_set_style_bg_color(lv_scr_act(), lv_color_black(), LV_PART_MAIN);
    lv_refr_now(NULL); // Refresh the display immediately
    esp_deep_sleep_start();
  }
  
  // Update last weight value
  lastWeight = currentWeight;
  
  // Check battery status
  float batteryStatus = getBatteryVoltage(); // Update the battery status
  
  if (batteryStatus < 3) // Check if battery voltage is below 3V
  {
    Serial.println("Battery voltage is low. Entering deep sleep...");
    // Display low battery message before going to deep sleep
    lv_label_set_text(label_weight, "Low battery");
    lv_refr_now(NULL); // Refresh the display immediately
    delay(2000); // Wait for 2 seconds to show the message
    // Flush the screen to black before going to deep sleep
    lv_obj_clean(lv_scr_act());
    lv_obj_set_style_bg_color(lv_scr_act(), lv_color_black(), LV_PART_MAIN);
    lv_refr_now(NULL); // Refresh the display immediately
    esp_deep_sleep_start();
  }
  
  // Process BLE tasks
  processBLE();

  // LVGL task handler
  lv_task_handler();
  delay(10);
}

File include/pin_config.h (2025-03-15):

#pragma once

/*
#define WIFI_SSID             "SSID"
#define WIFI_PASSWORD         "Password"

#define WIFI_CONNECT_WAIT_MAX (30 * 1000)

#define NTP_SERVER1           "pool.ntp.org"
#define NTP_SERVER2           "time.nist.gov"
#define GMT_OFFSET_SEC        0
#define DAY_LIGHT_OFFSET_SEC  0
#define GET_TIMEZONE_API      "https://ipapi.co/timezone/"
*/

#define LV_DELAY(x)                                                                                                                                  \
  do {                                                                                                                                               \
    uint32_t t = x;                                                                                                                                  \
    while (t--) {                                                                                                                                    \
      lv_timer_handler();                                                                                                                            \
      delay(1);                                                                                                                                      \
    }                                                                                                                                                \
  } while (0);

#define TFT_DC        16
#define TFT_RES       15
#define TFT_CS_0      13
#define TFT_CS_1      14
#define TFT_MOSI      18
#define TFT_SCK       17


#define PIN_IIC_SCL   11
#define PIN_IIC_SDA   10
#define PIN_TOUCH_INT 12
#define PIN_TOUCH_RES 9

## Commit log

2025-03-16 Update main.cpp
    Added stop timer to tare function
2025-03-16 Timer was not working as intended
    Fixed timer starting at 1 instead of 0
    [main.cpp]
2025-03-20 Fixed a halting issue
    [main.cpp]
2025-03-20 Fix
    Accidentally broke tare in the last fix, should be fine now
    [main.cpp]
2025-03-23 Added wifimanager
    Added wifimanager to make it more user-friendly and made it a separate task to prevent halting.
    [main.cpp]
2025-04-01 Added a better OTA handler
    [min_spiffs.csv]
2025-04-01 spelling error
    [Vekt_mold.SLDPRT]
